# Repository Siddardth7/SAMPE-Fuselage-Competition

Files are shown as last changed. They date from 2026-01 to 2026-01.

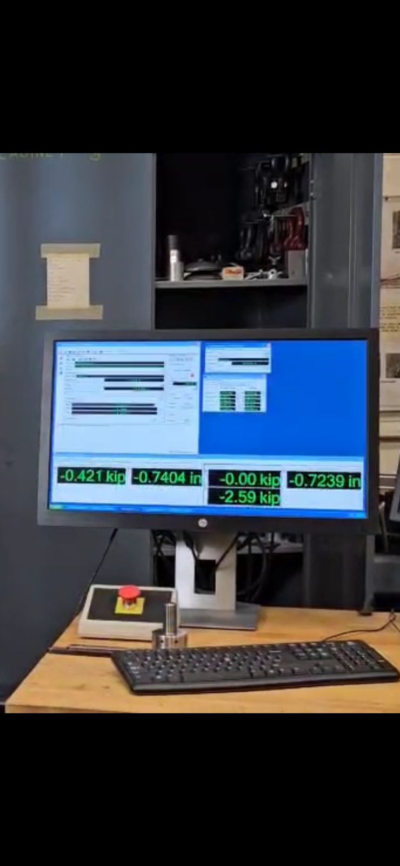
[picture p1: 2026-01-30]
images/utm_results.png

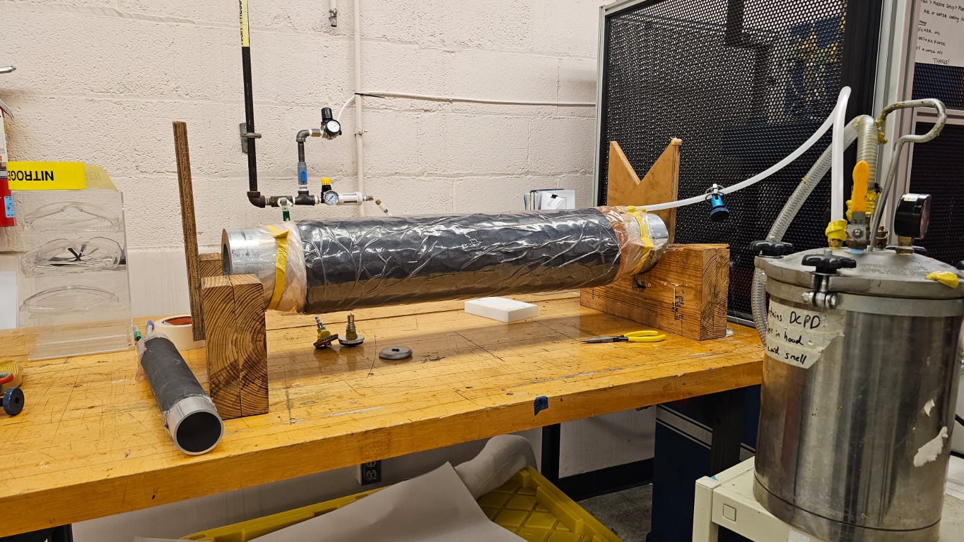
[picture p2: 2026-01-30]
images/vacuum_bagging_setup.jpg

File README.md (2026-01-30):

# SAMPE Fuselage Competition (2024‑2025)

## Overview

This repository contains the design, analysis and manufacturing records for a student‑built composite fuselage section created for the 2025 **SAMPE Student Chapter Fuselage Competition**.  The aim of the competition is to design, fabricate and test a glass‑fibre fuselage section that satisfies strict geometric constraints while withstanding at least **1 000 lbf** in three‑point bending with **< 1 inch** deflection.  Our team at the University of Illinois developed a sandwich fuselage using an E‑glass/epoxy skin and Nomex honeycomb core, optimized the laminate through analytical, numerical and experimental methods, built the part via vacuum‑bagged prepreg layup and autoclave cure, and validated the final structure in a universal testing machine.

## Objective

The project’s objectives were to:

* Comply with the **SAMPE fuselage design rules** (≥ 24 in length, 5.5–6 in diameter, four door cut‑outs, fibreglass only) and achieve a minimum **load capacity of 1 000 lbf** with less than **1 inch deflection**.
* Minimise weight while maintaining bending stiffness by selecting the appropriate number of plies, fibre orientations and core thickness.
* Design cut‑outs and stiffeners to minimise stress concentrations around the door openings.
* Develop a repeatable manufacturing process using prepreg layup, vacuum bagging and autoclave cure.
* Demonstrate the finished fuselage in a three‑point bending test and document performance.

## My Role

As part of a four‑person team I:

* Generated the **CAD model** of the fuselage and cut‑outs in SolidWorks and prepared drawings for manufacturing.
* Carried out **Classical Laminate Theory** calculations and wrote a **Python optimisation script** (`code/layup_optimizer.py`) to explore symmetric, balanced stacking sequences.  The program uses simulated annealing to maximise bending stiffness while controlling weight and enforcing symmetry and ply‑percentage constraints.
* Performed **finite‑element simulations** in Abaqus to estimate displacements and stresses for candidate layups; the chosen configuration produced ~2.5 mm displacement under design load.
* Evaluated manufacturing methods and selected **vacuum‑bagged prepreg layup with Nomex core** as the most cost‑effective process.  I documented risk sources (vacuum leaks, uneven pressure, resin pooling, porosity and environmental variability) and mitigation strategies.
* Led **layup and curing** in the composites lab, including core bonding, vacuum bagging, autoclave cure and trimming.  Process photos are available under the `images/` directory.
* Conducted the **three‑point bending test** and recorded load–deflection data.  The fuselage carried **≈ 2.6 kip** (≈ 2 590 lbf) at failure with **≈ 0.74 in deflection**, exceeding the competition requirements.
* Wrote the final design report, manufacturing report, risk assessment and presentation slides (see `docs/`).

## Technical Details

- **Materials:**
  - **Skins:** Woven **E‑glass/epoxy prepreg** (7781 E‑glass) chosen for cost and availability; S‑glass was analysed but deemed unnecessary after simulations predicted acceptable deflection with E‑glass.
  - **Core:** **Nomex honeycomb**, bonded between inner and outer skins to form a sandwich structure; core thickness selected based on stiffness–weight trade‑off.
  - **Adhesive:** Film adhesive (epoxy) used to bond core to skins.

- **Manufacturing & Analysis Methods:**
  - **Analytical design:** Classical Laminate Theory used to compute bending stiffness and first‑ply failure for candidate stacking sequences; results informed fibre orientation choices.  A **simulated annealing algorithm** (see `code/layup_optimizer.py`) searched for symmetric, balanced layups that maximise stiffness with minimum weight and 10 % ply‑orientation quotas.
  - **Finite‑element simulation:** 3D models built in **Abaqus** predicted a maximum displacement of ~2.5 mm for the selected layup under 1 000 lbf bending load.
  - **Manufacturing:**
    1. **Prepreg cutting:** Fibreglass prepreg, peel‑ply, release film, breather and vacuum bag were cut to size.  Core sections were cut from Nomex honeycomb.
    2. **Layup:** Layers were wrapped on a mandrel in the sequence [–45/0/45/90/Core/90/45/0/–45]s (symmetric with eight plies per face).  Light debulking was performed every four plies to remove air.
    3. **Core bonding:** Nomex core bonded to first skin using film adhesive; second skin laid on top.
    4. **Vacuum bagging:** The laminate stack was sealed with bag film, breather and tape; vacuum ports were attached, and the assembly was leak‑checked.
    5. **Autoclave cure:** Cured according to the prepreg cycle (ramp to cure temperature, hold, then cool).  A small amount of shrink tape provided radial compression.
    6. **Trimming & cut‑outs:** After cure, the fuselage was trimmed to 24 in length and four circular cut‑outs (≈ 2.5 in diameter) were machined per competition rules.
  - **Testing:** A **three‑point bending test** on a universal testing machine measured load and deflection.  The fuselage withstood **≈ 2.59 kip** before catastrophic failure with maximum deflection **≈ 0.74 in** at mid‑span, meeting the < 1‑inch deflection requirement at the specified 1 000 lbf load.

- **Tools & Software:** SolidWorks, Abaqus/CAE, Python (NumPy), Pandoc, universal testing machine (Instron), autoclave, vacuum pump and leak detector.

- **Standards & Constraints:** All work followed the **SAMPE Student Chapter Fuselage Contest Rules (2024‑25)**, which prescribe geometry (24 in minimum length; 5.5–6 in diameter), material restrictions (fibreglass only), four door cut‑outs per fuselage, and a design load of 1 000 lbf with ≤ 1 in deflection.

## Key Results

| Metric | Value / Outcome |
|---|---|
| FEA predicted deflection | ~2.5 mm at 1 000 lbf (Abaqus) |
| Final layup | [–45/0/45/90/Core/90/45/0/–45]s |
| Manufactured length | 24 in |
| Outer diameter | 6 in (5.5 in inner diameter) |
| Number of cut‑outs | 4 (2 per side, 2.5 in diameter) |
| Test load at failure | ≈ 2.59 kip (≈ 2 590 lbf) |
| Deflection at failure | ≈ 0.74 in |
| Weight | (not measured) |

## Engineering Challenges

* **Layup symmetry and balance:** Achieving a symmetric, balanced laminate with the required 0°, ±45° and 90° percentages while minimising ply count was non‑trivial.  The simulated annealing tool accelerated this search and identified an eight‑ply skin as optimal.
* **Vacuum integrity:** Minor leaks during vacuum bagging caused inconsistent consolidation.  The team used leak detectors and extra sealant tape to reduce porosity.
* **Core bonding:** Ensuring full adhesion between Nomex and skins without crushing the core required careful pressure control; shrink tape and breather materials assisted.
* **Stress concentration around cut‑outs:** The door cut‑outs introduced local stress raisers.  Choosing a woven prepreg and adding extra plies around openings mitigated these effects.
* **Testing fixture compliance:** Aligning the fuselage in the three‑point bending rig and preventing rotation during loading demanded fixturing modifications.

## What This Demonstrates

This project showcases skills and experience relevant to composites design and manufacturing roles:

* **Composite structures:** Deep understanding of classical laminate theory, ply orientation effects and sandwich construction.
* **Structural simulation:** Experience using Abaqus for FEA and interpreting deflection, stress and failure results.
* **Algorithm development:** Implemented a simulated annealing optimiser to automate layup selection under multiple constraints.
* **Hands‑on manufacturing:** Fabricated a composite fuselage via prepreg layup, vacuum bagging and autoclave curing; performed trimming and finishing.
* **Testing & validation:** Conducted a full‑scale three‑point bending test and analysed load–deflection behaviour against design requirements.
* **Risk management:** Identified and mitigated risks in vacuum bagging (leaks, uneven pressure, resin pooling, voids and environmental factors), documenting strategies for quality control.
* **Team collaboration & communication:** Coordinated with teammates to balance design, analysis and manufacturing tasks and produced comprehensive reports and presentations.

## Documentation

The `docs/` folder contains the full project documentation:

| File | Description |
|-----|---|
| **AE526_Final_Report.pdf** | Detailed design report including literature review, analytical calculations, FEA results and first ply failure analysis. |
| **Manufacturing_Report.pdf** | Comprehensive manufacturing report covering material selection, process evaluation, detailed prepreg layup steps, vacuum bagging procedure, autoclave cure schedule, risk assessment and mitigation strategies. |
| **Risk_Analysis.docx** | In‑depth risk and mitigation analysis for vacuum bagging, highlighting critical failure modes (bag leaks, uneven pressure, resin pooling, porosity, environmental factors) and recommended controls. |
| **Layup_Info.docx** | Literature survey summarising optimal ply counts, fibre orientations and symmetric/balanced stacking sequences for cylindrical fuselages. |
| **Competition_Rules.pdf** | Official SAMPE Student Chapter Fuselage Competition rules (2024‑25 edition). |
| **AE526_Presentation.pdf** | Slide deck summarising the design, manufacturing process and results for the course presentation. |

Process photos, FEA plots and test images are in the `images/` folder, while source code for the layup optimiser resides in `code/` and the SolidWorks model in `cad/`.

## Notes

* **NDA considerations:** All information provided here pertains to a student competition project and is publicly shareable.  No proprietary data or confidential sponsor information is included.
* **Future work:** Improving core modelling in simulations, exploring S‑glass skins for higher stiffness, performing additional testing to measure weight and failure modes, and refining cut‑out reinforcement methods.

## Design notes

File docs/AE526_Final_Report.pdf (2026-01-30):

AE526: Advanced Composites Manufacturing | Final Design Report

## FINAL DESIGN REPORT: FUSELAGE

Harsha Pandey, Ushasree Perakalapudi, Siddardth Pathipaka, Abhishek Iyer University of Illinois, Urbana-Champaign

The report presents the design and analysis of a composite fuselage section. The fuselage design adheres to specific constraints as laid out in the guidelines. Through theoretical calculations and simulations is done to determine the optimal design choices. Material selection and their justification is presented. Vacuum bagging was identified as the most suitable manufacturing method, considering its cost-effectiveness and ability to produce high-quality laminates. The results from the theoretical calculations, simulations are discussed. Future endeavors include optimizing the layup configuration and conducting simulations to assess the impact of door cutout positions on stress concentrations.

## 1. INTRODUCTION

NASA’s ACEE (NASA Aircraft Energy Efficiency) Program aimed to build and design composite components for commercial aircraft. Initial parts included fairing panels, spoilers, and skins. The Airbus A310 featured multiple composite parts, followed by the A320 which had an all-composite empennage. Composite materials improved performance in rotorcraft and general aviation. Boeing and Bell used composites in the V-22 airframe, reducing weight, costs, and part count. [46]. Recent advancements in aircraft materials and manufacturing have led to the development of innovative composites, such as Al-based, Mg-based, Ti-based alloys, ceramics, and polymers. These materials have exceptional properties and are widely used in the aerospace industry for cost reduction, weight reduction, and extended component service life. Composites are also used in military and commercial aircraft, as well as Unmanned Aerial Vehicles (UAVs). [47] Aircraft development in the early 1900s used sitka spruce and tightly woven wool fabric with varnish. Aluminum was experimented for weight savings due to limited power [Starke and Staley]. Strength-to-weight ratio was the primary criterion. While lightweight is important, current design considers time duration, fuel savings, range, and a history of multiple aircraft accidents. Now, new materials like high-strength aluminum alloys, titanium alloys, and carbon fiber-reinforced polymer composites have significantly enhanced performance. Material properties, chemistry, processing, and component design have led to substantial improvements. Different components have varying loading profiles, necessitating distinct design and materials selection. [48]

The advancements in material selection correspondingly warranted changes and advancements in manufacturing techniques, especially as composites were increasingly inculcated into the design of aircraft. The ATCAS program was sponsored by NASA with a focus on developing cost and weight-efficient composite technologies. Key manufacturing processes included Automated Fiber Placement (AFP) and Resin Transfer Molding for manufacturing of the frames and pultrusion for floor beams. Significant resources were invested into the program to optimize the manufacturing process to develop and optimize the processes for efficient and reliable fabrication of the composite structures. New manufacturing methods such as Outer-mold-line (OML) and inner-mold-line tooling (IML) were introduced to facilitate sandwich and stiffened-skin structures. The ATCAS program emphasized the importance of balancing and including the discussions of manufacturing considerations and techniques at the design stage itself to improve costing and throughput. [49]

In the following report, the design and analysis of a completely composite-based fuselage section is discussed. Theoretical and Analytical calculations are undertaken to ensure sound understanding and correlation between each other. Further, prospective materials (from the glass fiber family and relevant resin transfer system), fiber orientation, layups, manufacturing techniques and their effects on the strength of the composite are discussed. Analytical simulations and their agreement with theory is also shown. Finally, the manufacturing possibilities and methods are presented for the composite fuselage assembly. Both best cases as well as cost-effective manufacturing methods are shown.

## 2. METHODOLOGY

Design methodology usually started with gaining information on the market’s sentiments, and requirements. It is always recommended to gain an insight from the stakeholder’s point of view, as the new product generally caters to their requirements. Therefore, the stakeholder sentiments are obtained through a survey known as the Voice of the Customer (VOC), which aims to capture the most critical requirements the stakeholder thinks are an absolute necessity or the bare minimum in any new product introduced to the market. Next, theoretical calculation is undertaken based on metrics which are derived directly from the stakeholder’s feedback. This helps in the ideation of an initial iteration for the overall design, providing us with a complete baseline expectation of an agreeable design. Next, 3D simulations are done utilizing commercial software to get an understanding of how the product reacts to various loading conditions. Manufacturing methods are then discussed, in an ideal scenario as well as in the context of what is available at the Composites Manufacturing Laboratory at the University of Illinois.

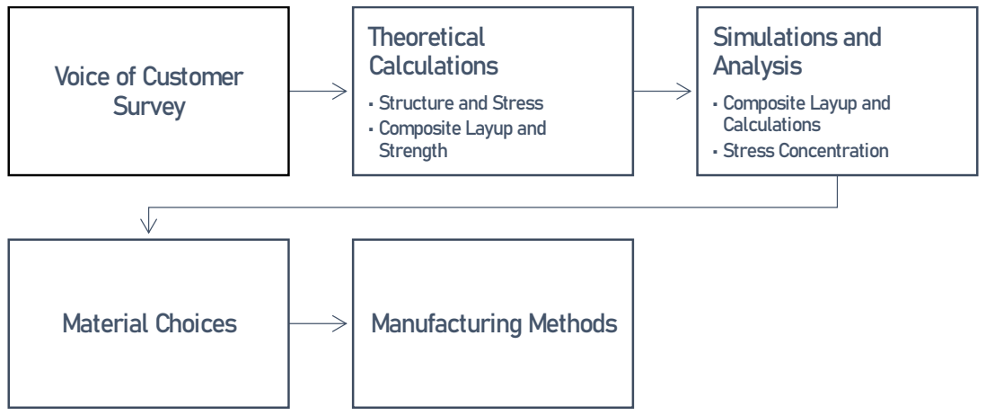
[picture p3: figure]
Voice of Customer Survey; Theoretical Calculations; • Structure and Stress • Composite Layup and Strength; Simulations and Analysis; • Composite Layup and Calculations • Stress Concentration; Material Choices; Manufacturing Methods

Figure 1: Methodology of the Fuselage Design Process

Figure 1 illustrates the overall design process which was followed for the development of the Fuselage.

## 3. IDENTIFYING REQUIREMENTS

There was very little need for a VOC survey in this context, as this design was being developed to be completely in compliance with rules and regulations laid out in the SAMPE Fuselage Design Competition guidelines.

As a result, the basic guidelines and broad constraints for the design were given as the following:

1. The design shall be capable of withstanding at least 1,000 lbf of load.
2. The design shall not deflect more than 1 inch in analysis at load requirement.
3. Fuselage shall be at least 24 inches in length.
4. Inner diameter shall not be less than 5.5 inches throughout the entire length of the fuselage.
5. Outer Diameter shall not be more than 6 inches throughout the entire length of the fuselage.
6. Fuselage shall include 4 cutouts at least 2 inches in diameter each.
7. Cutouts shall be at least 10 inches apart, and no more than 15 inches from each other’s closest edges.
8. Cutouts shall be at least 5 inches from the edge of the fuselage.
9. The fuselage shall be made of fiberglass.
10. A Nomex or Kevlar honeycomb core may be used.

The fuselage would be designed considering these initial design parameters.

## 4. CALCULATIONS

### 4.1 Theoretical Calculations

From the above provided requirements, we have a few values to utilize for our theoretical calculations. Consider the figure shown below:

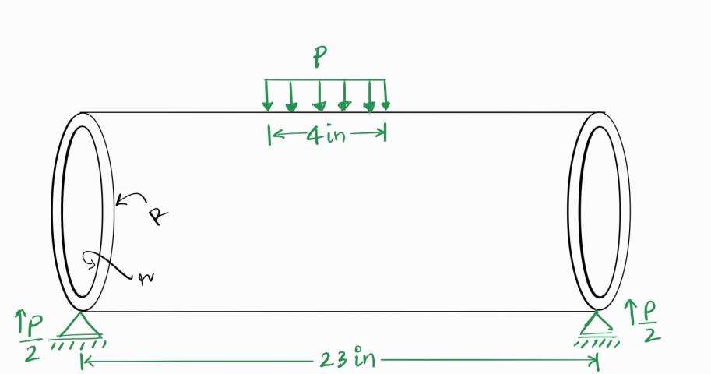
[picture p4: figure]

Indenter Load, P = 1000 lbf or 4448.22 N

Deflection, δ = 1 in or 25.41 mm

Length between the two supports of the Bending Fixture, L = 23 in or 584.2 mm

Inner Diameter, r = 5.5 in or 139.7 mm

Outer Diameter, R = 6 in or 152.4 mm

Length of the Fuselage = 24 in or 609.6 mm

The midpoint of the Fixture =

L
2

= 11.5 in or 292.1 mm

Following are the assumptions considered:

1. The material is Isotropic.
2. There are no laminates here, and the calculation done is for a solid hollow cylinder.
3. The distributed load while calculating has been normalized into a point load at the center of the fuselage.

Force measurement in tℎe Y direction (Tℎe Reaction force direction of

P
2

) is given by:

P − RA − RB = 0

or P −

P
2

−

P
2

= 0

or 4448.22 = P.
∴ tℎe equation is balanced. Tℎe Moment for B is given by:

4448.22 × 292.1 −

P
2

= 649662.531 Nmm

Tℎe neutral axis, y = 152.4 mm

I =

π
4

× [(76.2)

4 − (69.85)

4

] = 7783205.4141 mm⁴

∴ σ =

M × y
I

or σ =

(649662.531 × 76.2)
7783205.4141 | = 6.3604 MPa
We know tℎat δ = | FL
| 3
| 48 EI

or E =

FL

3
48 × δ × I

or E =

4448.22 × (584.2)

| 3
48 × 25.4 × 7783205.4141
or E = 93.4625 MPa

This initial calculation of the fuselage assumes a case of pure bending, typical for isotropic materials, e.g., steel. However, since the fuselage is going to be made of multiple layups of composite material, there will be out-of-plane forces involved making it imperative to consider the shear forces involved in future analyses.

Therefore, it is desirable that the effective Young’s modulus must incorporate not only the shear modulus but also the geometric factors (there are going to be cutouts in the final product) more accurately to reflect the behavior of the fuselage composite. Composites inherently show anisotropic properties, meaning stiffness and strength varying in direction. For the composite calculations executed, the team also felt that it was necessary to incorporate a factor of safety to account for some terms which were not considered. This also accounts for any other issues which may be encountered such as manufacturing defects, voids, and other environmental influences. The factor of safety also increases the fuselage’s ability to withstand loads.

Moreover, the requirement for cutouts introduces localized stress concentration around the perimeter of the cutout, which can be characterized by the stress concentration factor kt, which for circular geometries is approximately 3. This elevated stress must be factored into the bending stress to compute an effective bending stress especially when evaluating first ply failure.

### 4.2 Composite Analysis

The team followed reference [44] for the calculation of the composite layup. The paper was able to adapt the CLT usually used for a flat plate to the shape of a hollow cylinder among other shapes. The paper has experimental results to prove that the deflection was consistent with the analytical results up to a certain limit. The equation given by the paper for a Composite Tube for identifying the maximum deflection was:

wt = P {
Rm
16λEyWaT

[(3π − 8) (
Rm
e

+ 1) + (
kπEy

Gyz )] + [
L

3
48(EI)eq

+

L

4(GA)eq]}

wℎere e = Rm −

T
ln Rm + 0.5T
Rm − 0.5T

, λ = 6.74 (

RC
Rm

) + 1.01

(EI)eq = π (A11 − (
A12

2

A22)) Rm
3 + 2π (B11 −
B12

2
B22) +
π
Rm

(D66 −
(D26

2
)

D22 )

+ π (A55 − (
A45

2

A44)) Rm

Ey =

1
a22

∗ T

, Gyz =

1
a44

∗ T

The best composite layup would be the layup producing the least deflection of all. Therefore, the team created an iterative program in Python which iterated through all possible stack orientations, calculating the deflection for each iteration. Since there was also a core to be used in the layup, most of the available thickness was taken up by the core, allowing only for 4 plies to be used on each half of the composite fuselage.

Due to the inability of some composite packages available on python to consider a core material as part of the entire composite, two separate variations of the code were tried to solve the same problem of including the core as part of the ABD matrix. Silva et. al [45] devised a method in which they added the two ABD matrices of the core and the composite ply layup separately, along with a residual term added to adjust the entire equation. Instead of calculating the residual term as given, the team decided it was best to consider a factor of safety while calculating the equivalent Young’s modulus, as not including the term simply underestimated the modulus value.

The code based on the Composipy package and the equations from Zhu’s paper yielded differing results based on the material properties entered. It was observed that we cannot escape the issue of the core being considered as one of the plies in the composite. This is an issue as the core does not contribute much to the integral properties of the composite itself, contributing to reducing the shear loading and the load distribution of the composite. Its other inferior properties such as E1 and E2 are very low in comparison to the S-glass/Epoxy properties. The codes can be perused in the Appendix section.

## 5. SIMULATION ANALYSIS

To validate the results and to verify whether the theoretical results agree with real-world, a few simulations were carried out. ABAQUS was used, as it has a simplified interface to model the layup of composites. The simulations showed that the average deformation irrespective of the layups (two layups with the core in between: [0/45/-45/90]s and [0/0/0/0]s ) was in the range of 2.5 mm. The stress increased when the plies were changed to be angled. This could be due to the interlaminar shear stresses between each ply, which could increase due to the orientation.

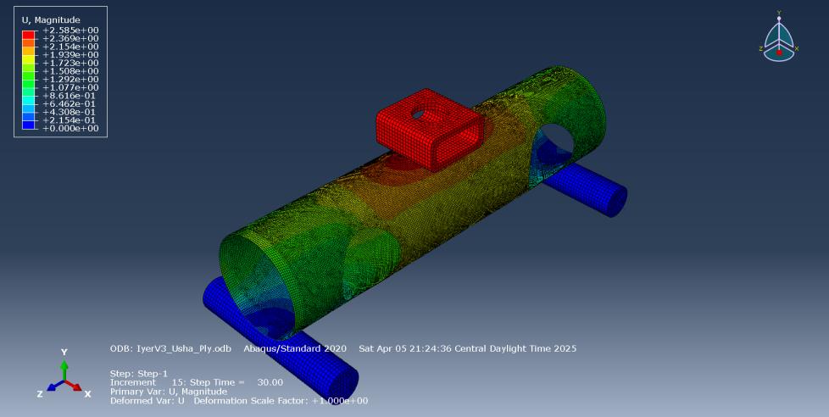
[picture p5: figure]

Figure 2: Maximum Displacement for the Ply Orientation [-45/0/45/90/Core/90/45/0/-45]

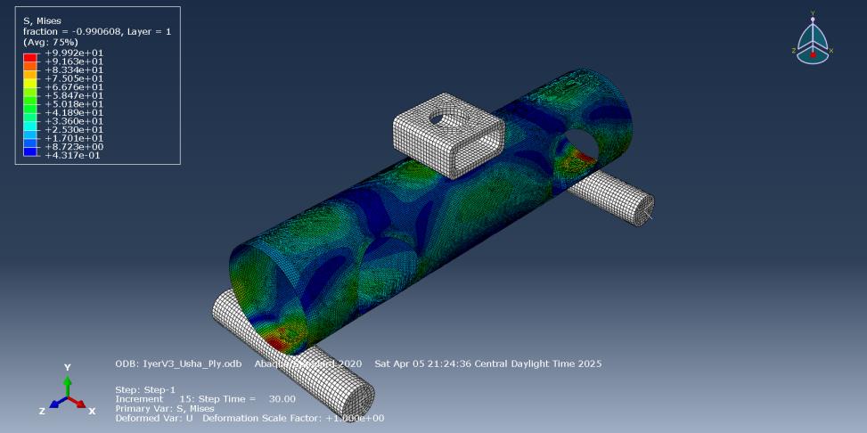
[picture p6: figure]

Figure 3: Stress Distribution for the Ply Orientation [-45/0/45/90/Core/90/45/0/-45]

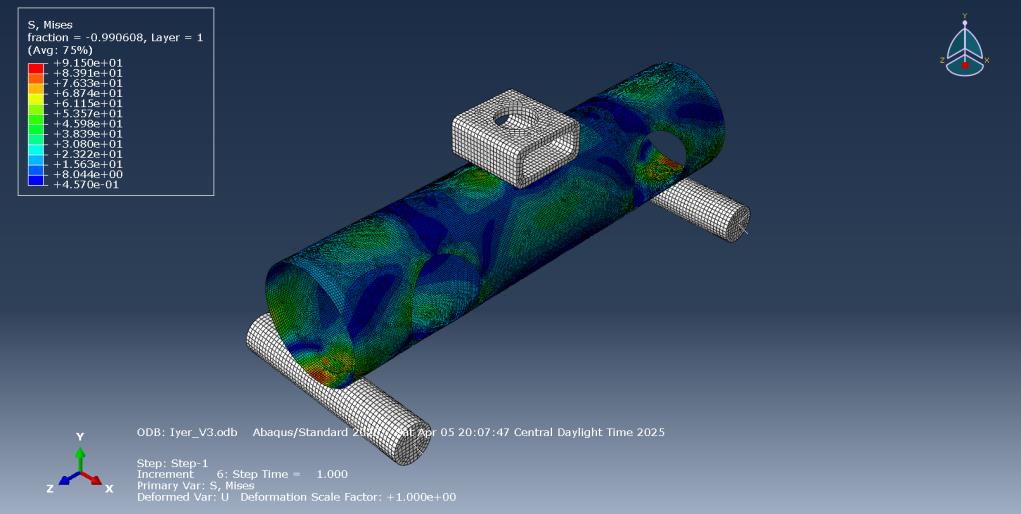
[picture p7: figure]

Figure 4: Stress Distribution for the Ply Orientation [0/0/0/0/Core/0/0/0/0]

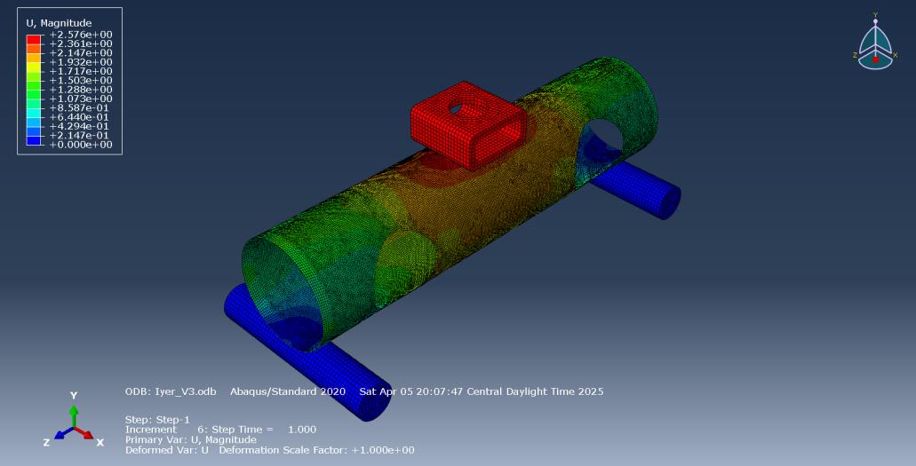
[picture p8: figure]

Figure 5: Maximum Displacement for the Ply Orientation [0/0/0/0/Core/0/0/0/0]

More research revealed that the core should have been modelled directly into the laminate assembly and therefore could have provided more accurate results. This should have been included previously, however due to a lack of time, it was not executed. Future work for the Manufacturing Report could include a simulation with respect to the same.

## 6. FIRST PLY FAILURE

A Glass fiber reinforced Epoxy laminate composed of 8 layers, including a core layer, was analyzed to determine the first ply to fail under bending loads by Tsai-Wu failure criterion. Each layer was defined by material properties in the local fiber axes and by an orientation angle measured relative to the global x-y axes. The procedure involved assembling the laminate stiffness matrices, computing curvatures from the applied bending moments, finding the global and then local stresses in each ply, and finally applying a failure criterion to identify the first layer that exceeds its allowable stress limits.

The analysis was implemented in Python using NumPy for matrix computations. The full stacking sequence, stiffness matrix assembly, curvature computation, and Tsai-Wu failure evaluation were automated. Stress and strain results were calculated for each ply under pure bending.Code can be found in the Appendix.

The compliance matrix S for each layer in local coordinates was constructed as follows. A unidirectional ply exhibits orthotropic behavior in its plane. Let E1, E2, G12, and ν12 be its In-plane moduli and Poisson ratio, respectively. Then the local compliance matrix is

The inverse of S was computed to give the local stiffness matrix Q.

A unidirectional layer oriented at an angle θ in the global x-y plane requires a transformation to obtain its global stiffness matrix Q̄.

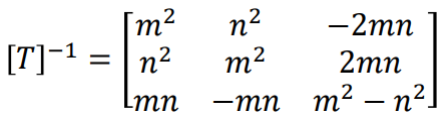
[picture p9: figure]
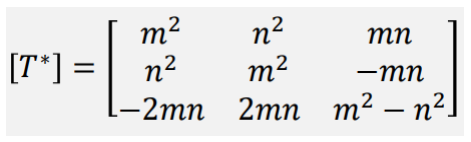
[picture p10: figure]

The laminate stiffness matrices A, B, and D were obtained by numerical integration through the thickness. Suppose the z coordinate is defined with the mid-plane at z = 0. For each layer k with a bottom surface hk−1 and a top surface hk, the stiffness integrals were carried out:

The sum of thicknesses from the bottom layer to the top produces the total laminate thickness, and the mid-plane defines z = 0.

In this case, one of the layers was designated as the core. Its thickness was larger than the surrounding plies, but its in-plane moduli were relatively small. This difference was reflected in its lower Q̄ contribution to A, B, and D. The resulting overall stiffness matrices included the entire stack, from bottom lamina through the core to the top lamina.

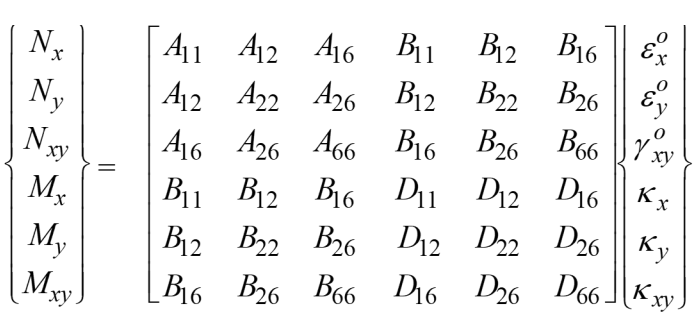
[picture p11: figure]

Being a symmetric laminate, the B vector was equal to zero. With A, B, and D known, a pure bending case with no in-plane loads was considered. The bending moment vector M was applied as per the loading conditions specified in the theoretical calculations.

The laminate curvature vector was solved from

In-plane strains at a distance z from the mid-plane were then calculated. For each ply, including the core, its local stiffness Q̄ was applied to this global strain to compute the in-plane global stress for each ply are calculated components in x and y directions plus xy shear.

A final transformation was then used to convert the global stresses to local fiber axes, that is σ1, σ2, and τ12.

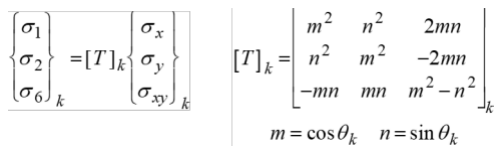
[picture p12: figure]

A ply failure criterion was applied to the local stress. The Tsai-Wu criterion, which can be stated in polynomial form as

Where,

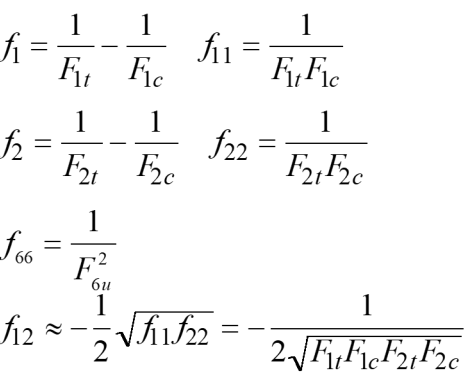
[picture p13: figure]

The strengths F1t, F1c, F2t, F2c, and F6 refer to tensile and compressive strengths in the fiber and transverse directions, plus in-plane shear strength. When the criterion was used, the index for each ply was computed in turn, starting from the bottom to the top. The first ply whose index exceeded 1 was designated as the first ply to fail. If the analysis included a core strength definition, that layer was also checked for in-plane failure; otherwise, the core was treated as having negligible in-plane strength and excluded from the failure checks.

This methodology accounted for each layer’s orientation, thickness, and stiffness, along with in-plane strengths in the fiber directions and shear. By computing local stresses under bending and testing them against these allowable limits, the analysis indicated which ply or layer including the core reached its critical stress level first.

A Classical Laminate Theory-based analysis was conducted to evaluate first ply failure under pure bending for various ply orientations. Multiple stacking sequences were examined, incorporating both symmetric and asymmetric configurations. Among the tested layups, the symmetric configuration [0∘

/45∘

/90∘

/45∘
]s, including a core layer, was found to be structurally effective under the applied maximum bending load. The stress distribution across the laminate thickness was assessed using the Tsai-Wu failure criterion, and no plies were found to fail at the specified loading conditions. Additionally, the computed maximum mid-plane deflection under this loading was 23 mm, indicating sufficient stiffness while maintaining failure resistance. This configuration can therefore be considered suitable for applications requiring both mechanical performance and reliability under flexural loads.

## 7. MATERIAL CONSIDERATION

### 7.1 Fiber Selection for Composite Fuselage

In composite structures, the choice of fiber reinforcement plays a critical role in determining mechanical performance, cost efficiency, and manufacturability. While high-performance fibers such as carbon fiber offer exceptional strength-to-weight and stiffness-to-weight ratios, their high cost often makes them impractical for certain applications. In this project, material selection was guided by established design guidelines, which specified fiberglass as the preferred reinforcement category. Among the available options, glass fibers were selected for further study as the primary reinforcement material due to their favorable balance of mechanical properties, cost-effectiveness, and availability. This makes them particularly well-suited for aerospace applications such as fuselage fabrication, where reliable performance must be achieved within budget and production constraints.

Glass fibers are recognized for their high tensile strength, good impact resistance, and ease of processing. Moreover, their widespread availability ensures a cost advantage over advanced fibers such as carbon or aramid. Among the glass fiber variants employed in aerospace applications, S-Glass and E-Glass are most frequently chosen due to their mechanical performance, cost-effectiveness, and widespread availability. These fibers fulfill demanding requirements for structural components, including high tensile strength, stiffness, and impact resistance.

Comparison of S-Glass vs. E-Glass:

Because of their extensive use and relevance to aerospace engineering, comparing S-Glass and E-Glass is crucial for identifying which fiber best satisfies the performance and cost targets of the fuselage design. This assessment focuses on key parameters such as tensile strength, stiffness, density, and impact resistance.

Mechanical Properties: Comparison of Key metrics from literature review :

Property | S-Glass | E-Glass | Advantage
Tensile Strength | 4600 Mpa | 3400 Mpa | +35% stronger
Elastic Modulus | 89 Gpa | 72 Gpa | +23% stiffer
Density | 2.53 g/cm³ | 2.54 g/cm³ | Almost same
Impact Resistance | High | Moderate | Better Durability

Table 1: Comparison of mechanical properties of S-glass and E-glass

Design-Specific Advantage:

S-Glass offers several distinct benefits over E-Glass for aerospace applications. Its 5.2% elongation, compared to E-Glass’s 4.7%, improves impact resistance in multidirectional laminates, while its higher fiber toughness reduces the risk of delamination during manufacturing. Additionally, its 30% greater compressive strength contributes to enhanced structural integrity around door openings and other high-stress areas.

After comparing S-Glass and E-Glass, S-Glass was chosen as the primary fiber for the fuselage design because of its superior mechanical properties. Its 35% higher tensile strength delivers a greater load-bearing capacity under bending forces, and the 23% increase in elastic modulus improves bending resistance while reducing deflection. Furthermore, its enhanced impact resistance makes S-Glass well-suited for regions experiencing stress concentrations or sudden loads, such as door cutouts or structural joints. Building on this selection, the next step involved evaluating different S-Glass variants to determine the most suitable option for the project.

Comparison of S-Glass Variants:

S-glass identified as the primary reinforcement material; the next step involves selecting a specific variant that best aligns with the fuselage design requirements. Different S-glass variants offer distinct properties optimized for various composite applications, where factors such as weave type, tensile strength, drapability, and cost can significantly affect the overall laminate performance. Comparing these variants enables the optimization of material selection by balancing design objectives and manufacturing processes. This below table examines three prominent S-Glass variants— AGY S-2 Glass, Hitex HS4 (SW220C), and Hexcel HexForce to determine which most effectively meets performance and manufacturing demands.

S-Glass Variants comparison table:

Variant | Tensile strength | Elastic Modulus | Density | Key Features | Relevance to our Project
AGY S-2 Glass | 4890 MPa | 89 GPa | 2.49 g/cm³ | Aerospace grade and High fatigue resistance | Best for load compliance Highest strength/stiffness. Reduces laminate thickness for outer diameter compliance.
Hitex HS4 (SW220C-90a) | 4200 MPa | 88 GPa | 2.53 g/cm³ | 4HS weave for drapability. Optimized for impact resistance. | Balanced choice. Stronger than E-Glass, easier to handle and cost-effective.
Hexcel HexForce S-Glass | 3500-4000 MPa | 85 Gpa | 2.63 g/cm³ | Plain weave. Options for pre-preg. Lower cost | Moderate Performance gains over E-glass and meets all project requirements.

Table 2: Comparison of properties of S-glass variants.

Based on the preceding comparison, AGY S-2 glass was selected for the fuselage design because of its superior mechanical properties. Its tensile strength of 4890 MPa, combined with an elastic modulus of 89 GPa, achieves an optimal stiffness-to-weight ratio. The lower density (2.49 g/cm³) further helps reduce overall laminate weight while maintaining structural integrity. In addition, its aerospace-grade quality and fatigue resistance make it particularly suitable for critical load-bearing sections, such as fuselage skins around door cutouts. Although other variants such as Hitex HS4 may offer advantages in drapability or cost, AGY S-2 Glass delivers the high-performance characteristics necessary to minimize laminate thickness while maximizing stiffness and strength.

### 7.2 Core Material:

Core materials play a crucial role in sandwich composite structures, providing a lightweight means of achieving the required strength, stiffness, and energy absorption. When developing high-performance sandwich structures, engineers commonly use materials like aluminum honeycomb cores due to their strength-to-weight ratio and cost-effectiveness. Polymer foam cores such as polymethacrylimide (PMI) foams are also frequently chosen for applications requiring superior mechanical properties, however the current guidelines constraints limit the choice to Nomex and Kevlar honeycomb cores. Hence are studied further to optimize the fuselage structure effectively.

Nomex and Kevlar honeycomb cores are frequently utilized in aerospace applications due to their favorable strength-to-weight ratios, fire resistance, and durability. Each variant presents distinct advantages and limitations, making a detailed comparison essential to identify the most suitable material for specific fuselage sections.

Property | Nomex Honeycomb core | Kevlar Honeycomb core
Shear Strength | 1.25 MPa (L-direction), 0.73 MPa (W-direction) | 1.75 Mpa (L-direction) (40% higher) . 1.02 MPa (W-direction)
Compressive Strength | 2.4 MPa | 3.36 MPa (40% higher than Nomex)
Density | 48 kg/m³ (Commercial grade) | 29-128 kg/m³ (Customizable based on size and thickness)
Cost | Lower (63.50 per sheet for 5mm thick and 48 kg/m³ | 20-30% higher than Nomex
Thermal Resistance | Service temperature: up to 180°C | Comparable to Nomex with better thermal stability under continuous exposure
Flame Resistance | Self-extinguishing to FAR 25.583 standards | Comparable to Nomex®, meets aerospace fire safety standards
Corrosion Resistance | Good moisture resistance with proper sealing | Excellent, resistant to chemical corrosion and environmental degradation.
Electrical Insulation | Moderate | High, suitable for electromagnetic shielding applications

Machining Difficulty | Moderate; easier to machine due to moderate rigidity

High; requires specialized tools due to abrasive nature and fragile cell walls.

Table 3: Comparison of properties of Kevlar and Nomex Honeycomb cores.

Based on the comparative analysis above, Nomex honeycomb cores are well suited for cost-sensitive applications demanding moderate strength and stiffness, making them ideal for fuselage components such as cabin floors and bulkheads. Kevlar honeycomb cores, in contrast, are more appropriate for high-stress regions requiring maximum shear strength and superior compressive performance. Strategic allocation of these materials ensures optimized structural efficiency and performance while complying with relevant design and material constraints

### 7.3 Introduction to Resin selection

Resins play a critical role in composite structures by binding reinforcing fibers, transferring loads between fibers, and providing protection against environmental factors. The resin matrix significantly influences the overall mechanical properties, chemical resistance, and thermal stability of composite materials. In aerospace applications, where high strength-to-weight ratios and durability are paramount, selecting an appropriate resin system is essential for maintaining structural integrity and optimal performance.

The resin systems selected for comparative analysis below were chosen based on their relevance to aerospace applications and their capability to satisfy specific performance criteria for composite fuselage structures. Epoxy, vinyl ester, polyester, and polyurethane resins were compared based on their mechanical properties, chemical resistance, and compatibility with S-glass fibers. By comparing these resin systems in terms of tensile strength, elastic modulus, shrinkage, chemical resistance and manufacturability, the analysis aims to determine the most suitable resin for fuselage design applications.

Rationale table for different types of resin systems:

Resin | Tensile Strength (MPa) | Elastic modul us (GPa) | Shrin kage | Chemical resistance | Compatibility with Fiber (S-Glass) | Performance Summary
Epoxy | 70-100 | 3-4 | <1% | Excellent resistance to moisture, solvents, and high temperatures (up to 150°C) | Fully compatible with S-glass; forms strong bonds with fibers due to high adhesion properties. Quick wet-out ensures uniform fiber impregnation | High strength and stiffness and strong bonding with S-glass minimizes delamination risks.
Vinyl Ester | 60-80 | 2.5-3 | <2% | Excellent resistance to acids, alkalis, and solvents | Fully compatible with S-glass; provides good fiber wet-out and adhesion | Affordable and tough but lower stiffness may result in higher deflection under load.
Polyest er | 40-70 | 2-2.5 | ~4% | Poor to moderate chemical resistance; susceptible to degradation over time in harsh environments | Limited compatibility with S-glass; weaker bonding compared to epoxy or vinyl ester | Limited mechanical performance
Polyure thane | ~50 | ~1.5 | <1% | Good resistance to solvents but limited durability | Compatible but does not provide strong bonding strength compared to epoxy or vinyl ester | Tough but lacks stiffness required for structural applications.

under cyclic
loads

Table 4: Comparison of properties of different resins

Based on the comparative analysis presented, epoxy resin demonstrates the highest mechanical performance among the evaluated options, aligning well with the requirements for composite fuselage designs. Its enhanced tensile strength and elastic modulus as detailed in above table ensure the stiffness and strength essential for load-bearing fuselage structures. Additionally, epoxy resin provides superior bonding capabilities with S-glass fibers effectively, minimizing the risk of delamination. Its compatibility with vacuum bagging techniques further contributes to a reliable and consistent manufacturing process. Although other resin systems possess certain advantages such as the cost effectiveness of polyester or the toughness characteristics of polyurethane, epoxy resin offers the most balanced and advantageous set of properties, meeting the demanding performance criteria required for aerospace fuselage applications.

### 7.4 Composite Layup Design:

Designing an effective composite layup for the fuselage is crucial for achieving the required structural performance while minimizing weight. This section presents the rationale behind the chosen layup design, examines the role of individual ply orientations and describes the methodology for optimizing the stacking sequence.

Role of Ply orientation in composite laminates:
Composite laminates derive their unique mechanical characteristics from the orientation of the individual plies. Each ply orientation addresses a specific structure need, contributing to the overall performance.
0° Plies: the primary function of 0° plies is to carry axial loads along the fuselage’s longitudinal axis. By aligning fibers at 0°, these plies maximize tensile and compressive strength in that direction, effectively resisting bending forces. However, an overreliance on 0° plies can concentrate stresses at ply interfaces, increasing the likelihood of delamination. Consequently, these plies are typically complemented by other orientations to mitigate stress concentrations. 45° Plies: plies oriented at 45° are essential for resisting shear forces and enhancing impact resistance. Shear stresses arise from in-plane loads acting parallel to a surface, and ±45° orientations distribute these forces more effectively. These plies also dissipate energy during impacts and dynamic loading, making them especially important in areas prone to shear forces or sudden loads, such as door cutouts or structural joints.
90° plies: Plies oriented at 90° provide lateral stability by resisting transverse loads perpendicular to the primary load direction. Although they contribute minimally to bending stiffness, these plies help maintain structural stability in cylindrical fuselage designs by counteracting hoop stresses from internal or external forces.

Multidirectional Layups:
Combining 0°, ±45°, and 90° plies in a symmetric, balanced configuration provides an optimal balance of stiffness, strength and weight. A commonly recommended stacking sequence is [0/45/90/45) s], which leverages 0° plies for axial stiffness, 45° plies for shear strength and impact resistance, and 90° plies for lateral stability. This approach minimizes stress concentrations and achieves more uniform load distribution.

Experimental evaluations show that while unidirectional laminates (12) offer high flexural strength, they are prone to brittle failures under transverse loads. Multidirectional laminates on the other hand, distribute stresses across various fiber orientations, thereby improving damage tolerance and reducing the risk of delamination.

Layers and thickness Optimization:
The total number of layers in a composite laminate significantly influences bending stiffness and overall mass. A minimum of three plies (approximately 0.53 mm in thickness) is necessary to prevent porosity and moisture ingress, thus preserving structural integrity. For aerospace fuselages exposed to bending and impact loads, 36-40 layers typically provide a suitable balance between stiffness and weight.

### Symmetry:

Symmetric and balanced layups are pivotal for minimizing residual stresses and preventing delamination during manufacturing or under operational loads. Symmetry helps distribute curing and thermal expansion stresses evenly throughout the laminate, reducing the likelihood of warping or twisting.

## 8. MANUFACTURING

### 8.1 Introduction to Manufacturing Plan Selection

This section analyzes potential manufacturing methods for fabricating a high-performance composite fuselage, integrating considerations of structural integrity, cost-effectiveness, design flexibility, and process scalability. Various methods are evaluated based on their alignment with design and performance objectives, and efficiency in resource usage. The final selection is justified through a structured decision matrix that accounts for critical factors identified in the literature review.

The manufacturing methods which were considered for this decision matrix are:
Change the order and write that which are most suitable in the beginning
1. Vacuum Bagging
2. Additive Manufacturing
3. Automated fiber placement (AFP)
4. Resin Transfer Molding (RTM)
5. Filament Winding
6. Hand Layup

The literature review identified vacuum bagging as the most efficient manufacturing method for composite fuselage structures due to its optimal balance of quality, performance, and cost-effectiveness. Vacuum bagging is good in producing high-strength, lightweight components characterized by uniform thickness and minimal defects, qualities particularly important in aerospace applications. To ensure a good understanding of the available manufacturing methods, this section briefly introduces each method, focusing on their respective processes, advantages, disadvantages, and suitability for fuselage manufacturing. Methods such as hand layup, resin transfer molding (RTM), filament winding, additive manufacturing (3D printing), and automated fiber placement (AFP) are studied to provide a comparative analysis that highlights their relative strengths and limitations within the context of fuselage manufacturing. This comparative overview establishes the rationale for selecting vacuum bagging as the preferred technique while recognizing the specific advantages of alternative manufacturing methods for specialized applications.

Vacuum Bagging

The vacuum bagging process involves sealing layers of fiber under a vacuum bag to ensure uniform pressure during curing. This technique is designed to consolidate the laminate effectively while simultaneously removing excess resin and trapped air. By creating a controlled environment under vacuum pressure, the fibers are compressed uniformly, resulting in a more compact and cohesive structure. The vacuum bag acts as a barrier, maintaining consistent pressure throughout the curing process, which is critical for achieving optimal laminate quality.

Vacuum bagging offers several advantages over traditional hand layup methods. One of its key benefits is improved consolidation, which leads to reduced void content within the laminate. This results in a stronger and more durable composite structure. Additionally, vacuum bagging provides more consistent thickness across the laminate compared to hand layup techniques, ensuring uniformity in structural properties. The method also delivers higher strength-to-weight ratios and more consistent quality, making it particularly beneficial for medium-sized fuselage structures. However, there are some disadvantages associated with this process. Vacuum bagging requires additional equipment such as vacuum pumps and bagging film, which can increase costs slightly compared to hand layup methods. Furthermore, operator proficiency is essential to prevent leaks during the process, as the maximum pressure achievable is limited to atmospheric pressure (approximately 14.7 psi).

Vacuum bagging is commonly employed for primary fuselage structures where moderate strength and weight efficiency are essential. Its ability to produce consistent and high-quality laminates makes it an ideal choice for applications requiring reliable performance in medium-sized composite components. While it may not be suitable for all manufacturing scenarios due to its equipment requirements and cost considerations, vacuum bagging remains a preferred method for achieving structural integrity in aerospace applications where strength-to-weight ratios are critical.

Additive Manufacturing (3D Printing):

Additive manufacturing, commonly referred to as 3D printing, is a process in which composite materials, such as carbon fiber-reinforced thermoplastics, are deposited layer by layer to construct parts. This technique eliminates the need for extensive tooling and allows for the precise fabrication of components directly from digital designs. By building parts incrementally, additive manufacturing offers a highly controlled and efficient method for producing composite structures while minimizing material waste.
The advantages of additive manufacturing are significant, particularly in terms of design flexibility. This method enables the creation of intricate geometries and integrated features that would be challenging or impossible to achieve with traditional composite fabrication techniques. Additionally, additive manufacturing excels in rapid prototyping, allowing engineers to quickly test and iterate designs with minimal material waste. Despite these benefits, there are notable disadvantages. The mechanical properties of parts produced through additive manufacturing may be inferior to those achieved using conventional composite methods. Furthermore, this process is generally restricted to smaller scale parts and offers limited material options compared to traditional techniques.

Additive manufacturing is particularly suited for prototyping fuselage components that require complex internal structures or lightweight core designs. Its ability to produce intricate geometries and lightweight parts makes it ideal for applications where design complexity and efficiency are prioritized. While it may not be suitable for large-scale production or high-performance structural components due to its limitations in mechanical properties and material selection, additive manufacturing remains a valuable tool for innovation in aerospace prototyping and lightweight design.

Automated Fiber Placement (AFP):

Automated Fiber Placement (AFP) is a highly advanced manufacturing process that utilizes robotic systems to deposit prepreg tapes onto a mold with exceptional precision. This process involves controlling fiber orientation and thickness to ensure optimal structural performance. The fibers, typically carbon or glass, are pre-impregnated with resin and placed in narrow strips, known as "tows," which are compacted and heated during the deposition process. The robotic system ensures repeatable accuracy, enabling the fabrication of complex geometries and high-quality composite structures. AFP is widely employed in aerospace manufacturing to create large-scale components such as fuselage sections and wing spars, where precise material placement is critical for achieving desired mechanical properties [3] (https://en.wikipedia.org/wiki/Automated_fiber_placement)[5] (https://www.addcomposites.com/post/overview-of-automated-fiber-placement-process)[7]. (https://www.wevolver.com/article/what-is-automated-fiber-placement-afp-in-composites-manufacturing)

AFP offers numerous advantages that make it a preferred method for composite manufacturing in aerospace applications. Its unmatched precision in fiber placement minimizes material waste and ensures consistent quality across large, complex structures. This precision also allows for optimized fiber orientations, enhancing the strength-to-weight ratio of the final product. Additionally, AFP significantly reduces production time compared to manual methods, as robotic systems can operate continuously with minimal downtime [2] (https://www.addcomposites.com/post/what-is-automated-fibre-placement-afp)[5] (https://www.addcomposites.com/post/overview-of-automated-fiber-placement-process)[6]. (https://www.wanlitex.com/news/understanding-the-principles-advantages-disa-77085396.html) However, AFP comes with notable disadvantages. The equipment and operational costs are extremely high, requiring substantial capital investment. Furthermore, skilled operators and programming expertise are essential to manage the system effectively and prevent defects such as material wrinkling or gaps during the layup process [4] (https://compositeskn.org/KPC/A303)[6] (https://www.wanlitex.com/news/understanding-the-principles-advantages-disa-77085396.html)[7]. (https://www.wevolver.com/article/what-is-automated-fiber-placement-afp-in-composites-manufacturing)

AFP is particularly suitable for manufacturing large composite structures in the aerospace industry, where weight optimization and repeatability are paramount. Its ability to produce high-performance laminates with precise fiber orientations makes it ideal for fuselage sections, wing spars, and other critical components requiring superior mechanical properties. While its high cost may limit its use outside of industries that can justify such investments, AFP remains an indispensable technology for applications demanding lightweight yet durable structures, such as commercial aircraft and spacecraft

Resin Transfer Molding (RTM):

Resin Transfer Molding (RTM) is a composite manufacturing process that involves positioning dry fibers within a closed mold and injecting resin under pressure to impregnate the reinforcement thoroughly. The resin, often combined with catalysts, flows into the mold cavity to saturate the fiber preform, ensuring uniform distribution and complete impregnation. Once the resin cures, the mold is opened, and the finished component is removed. RTM enables precise control over fiber orientation and resin content, making it suitable for producing high-performance composite parts with excellent dimensional accuracy and surface finishes. This process is widely used in industries such as aerospace, where lightweight and durable components are essential.

RTM offers several advantages that make it a preferred method for composite manufacturing. It produces high-quality parts with consistent dimensions and excellent surface finishes on both sides of the component. The process is particularly well-suited to complex geometries and integrated features, such as door cutouts, due to its ability to mold intricate shapes with tight tolerances. Additionally, RTM minimizes material waste by allowing near-net-shape production, reducing post-processing requirements. However, there are some disadvantages associated with RTM. The initial setup cost is high due to the need for specialized mold fabrication, which can be a barrier for small-scale production or prototyping. Moreover, achieving optimal results requires careful control of processing parameters and skilled operators.

RTM is ideal for manufacturing high-performance fuselage sections that demand tight tolerances and reduced post-processing. Its ability to produce lightweight yet durable components make it particularly valuable in aerospace applications where structural integrity and weight optimization are critical. While its high initial costs may limit its use in certain scenarios, RTM remains indispensable for applications requiring precision-engineered composite parts with complex geometries and superior mechanical properties

Filament Winding

Filament winding is a composite manufacturing technique that involves winding continuous fibers, such as carbon, glass, or aramid, onto a rotating mandrel. The fibers are impregnated with resin either before or during the winding process to ensure proper bonding and structural integrity. The mandrel rotates while a carriage system moves horizontally, laying down the fibers in predetermined patterns to achieve the desired orientation and thickness. Once the winding is complete, the resin is cured using heat or other methods, and the mandrel is removed to leave behind a hollow composite structure. This process is particularly effective for creating cylindrical or spherical components with high mechanical strength and precision.

Filament winding offers several advantages, making it an efficient and reliable method for composite manufacturing. It provides high hoop strength due to its ability to optimize fiber placement for cylindrical shapes, making it ideal for pressure vessels or structures subjected to hoop loading. The process efficiently utilizes continuous fibers, resulting in strong and lightweight components with minimal material waste. Additionally, filament winding is highly automated, ensuring repeatable quality and reducing labor costs. However, there are limitations to this method. It is primarily restricted to axisymmetric geometries and cannot accommodate complex shapes with openings, such as fuselage sections with integrated features. Furthermore, filament winding requires specialized equipment, which can be costly to acquire and operate.

Filament winding is particularly suitable for manufacturing fuselage tubes or pressure vessels that demand significant hoop strength and relatively simple geometries. Its ability to produce lightweight yet durable components make it an excellent choice for applications where internal pressure resistance is critical. While its geometric constraints limit its use for more intricate designs, filament winding remains a preferred method for producing high-performance cylindrical structures in industries such as aerospace, automotive, and industrial manufacturing.

Hand Layup

The hand layup process is one of the simplest and most widely used methods for composite manufacturing. It involves manually placing fiber reinforcements, such as fiberglass or carbon fiber, onto a mold that has been prepared with a release agent to prevent sticking. Resin is then applied using brushes, rollers, or similar tools to impregnate the fibers thoroughly. Additional layers of reinforcement and resin are added sequentially until the desired thickness is achieved. Once the layup is complete, the composite is allowed to cure, either at room temperature or under controlled conditions, before being removed from the mold. This process is straightforward and requires minimal equipment, making it accessible for small-scale production and prototyping.

Hand layup offers several advantages due to its simplicity and low initial cost. It requires minimal equipment and is highly adaptable, allowing for flexibility in layup orientation and design modifications. These characteristics make it particularly suitable for small-scale fuselage sections or prototypes where precision is not critical. However, the process has notable disadvantages. It is labor-intensive and time-consuming, which limits its efficiency for larger-scale production. Additionally, because it relies heavily on manual labor, there is a higher risk of defects such as inconsistent fiber alignment, elevated porosity, and air voids. These issues can result in parts with variable mechanical properties and inconsistent thickness.

The hand layup process is most suitable for producing small fuselage prototypes or non-critical components where tight tolerances and high mechanical performance are not required. Its low cost and adaptability make it an attractive option for experimental designs or projects with limited budgets. However, for applications requiring consistent quality or high production volumes, alternative methods such as vacuum bagging or resin transfer molding may be more appropriate. Despite its limitations, hand layup remains a valuable technique for specific use cases in composite manufacturing due to its versatility and accessibility.

Rationale with decision matrix:

The selection of the manufacturing method was conducted through a decision matrix which is employed to systematically evaluate each technique against a predefined set of criteria. This structured approach ensures an objective comparison by assigning weights to these criteria based on their relative importance in fuselage manufacturing, including factors such as cost efficiency, Compliance to rules, Quality of Finished Product, and Flexibility in Design. Each manufacturing method is subsequently scored against these weighted criteria to quantify its overall performance. This structured framework facilitates identifying the most effective manufacturing method while offering transparent and justifiable reasoning for the selection process.

Criteria | Weight | Justification
Cost | 3 | Budget constraints necessitate minimizing material, tooling, and labor costs.
Manufacturing Time | 4 | Efficient and timely production is a fundamental requirement
Quality of Finished Product | 5 | As the part needs to withstand load requirement and needs to have minimum defects to produce High quality product
Implementation | 4 | The method must be feasible given available skills, equipment, and resources.
Flexibility in Design | 4 | The ability to produce complex geometries (e.g., fuselage cutouts) is advantageous.
Compliance to rules | 5 | Must comply with established guidelines, requirements, and regulations.

Decision Matrix:

The decision matrix below shows the evaluation of various manufacturing methods for fuselage production. Each method is assessed against key performance criteria, with weights assigned to reflect their relative significance in fuselage manufacturing. This comparative framework enables a clear and systematic analysis, supporting the identification of the most appropriate manufacturing technique for fuselage applications.

Method | Cost (4) | Manufa cturing Time (4) | Quality (5) | Implementati on (4) | Flexibili ty (4) | Complia nce (5) | Total Weighted score
Hand Layup | 5 | 2 | 2 | 5 | 2 | 5 | 91
Vacuum Bagging | 4 | 3 | 4 | 4 | 3 | 5 | 105
RTM | 2 | 4 | 4 | 2 | 4 | 4 | 88
Automated Fiber Placement | 1 | 5 | 5 | 1 | 5 | 4 | 93
Filament Winding | 3 | 3 | 4 | 3 | 2 | 5 | 89
Additive Manufacturi ng | 2 | 4 | 4 | 3 | 5 | 5 | 101

Table 5: Decision matrix of comparing various manufacturing methods against criteria

Based on the outcomes of the comprehensive decision matrix, vacuum bagging is identified as the most suitable manufacturing method for composite fuselage production. This technique offers an optimal balance of cost efficiency, manufacturing quality, and ease of implementation, aligning well with the rigorous performance requirements of the fuselage. Although additive manufacturing presents significant potential for producing complex geometry and innovative designs, its current limitations in scalability and mechanical performance render it less practical for mid-scale fuselage fabrication. The established reliability of vacuum bagging, along with its capacity to deliver consistent and high-quality results, reinforces its selection as the preferred method for manufacturing high-performance composite fuselages.

### 8.2 Planned processing steps involved in vacuum bagging method:

The following section provides a systematic explanation of each step involved in the manufacturing approach, from material preparation and fiber layup to vacuum sealing and curing. This step-by-step outline illustrates how the method is implemented to optimize structural performance, minimize manufacturing defects, and fulfill the requirements associated with fuselage production.

### Mold Preparation:

1. Start by Thoroughly clean the Mold surface with acetone or other solvent
2. Apply Coating or releasing agent at least 2-3 times to avoid sticking and allow each coat to dry completely.
3. Lay Down a layer of mold release film or peel ply which can help in part removal and surface finish.

### Cutting and Material preparation:

1. Cut the fiberglass fabric to required dimensions allow extra for trimming
2. Pre-cut peel ply, release film, breather material, and vacuum bagging film

### Layup:

1. Apply the first layer of fiberglass fabric on to the mold ensuring no wrinkles.
2. Use a roller to remove any air bubbles.
3. Continue adding layers according to layup configuration [0/90/(±45)2s].
4. Between the layers use a roller to make sure there aren't any air bubbles.
5. Place peel ply over the final layer of fiberglass.

### Vacuum Bagging setup:

1. Apply release film over the peel ply.
2. Add breather material over the release film.
3. Position vacuum ports and tubing for even resin distribution.
4. Drape vacuum bagging film over the entire layup
5. Seal edges with sealant tape, making sure it's airtight seal.

### Resin Preparation:

1. Calculate the required amount of resin based on your layup.
2. According to our manufacturer’s specifications mix epoxy resin and hardener.
3. Degas the resin mixture in a vacuum chamber to remove air bubbles.

### Resin Infusion:

1. Connect the vacuum pump and create an initial vacuum to check for any leaks.
2. Once sealed, inject resin mixture through inlet ports.
3. Monitor the resin flow, make sure it's evenly distributed across the layup.
4. Clamp off resin inlet once resin covers entire layup and wet-out is achieved.

### Curing Process:

1. Maintain vacuum throughout the curing cycle
2. For heated cure, place the mold in an oven and for room temperature cure allow the part to cure for 24-48 hours.
3. Follow the resin manufacturer’s recommended cure cycle for time and temperature of curing.
4. Adjust vacuum pressure as needed or as recommended during cure.

### Post-curing:

1. Remove the part from the mold after curing
2. Place the part in an oven for any post-curing if it's recommended by the manufacturer.

### Finishing:

1. Trim excess material using cutting tools.
2. Use sandpaper to smooth the edges for a clean finish.
3. Cut out the door opening according to our calculations.
4. Sand the door openings for a smoother finish.

### Quality control:

1. Measure the dimensions to ensure they match with our calculations and meet our competition rules.
2. Perform visual inspection for any surface defects.
3. Do the tap testing to check for any voids or delamination.

### 8.3 Identified key risks with impacts

### Identification of potential risks in selected manufacturing method:

Vacuum bagging is a widely used and reliable method for manufacturing composite fuselages. However, certain risks remain inherent to the process. These risks arise from process complexity, environmental factors, and the need for precise execution. Each potential risk is described below, focusing on its relevance to fuselage manufacturing and accompanied by an assessment of its likelihood and impact.

### Potential Risks in Vacuum Bagging:

Leaks or Bag failures:
Leaks in the vacuum bag or improper sealing compromise vacuum pressure, leading to insufficient laminate consolidation. Poor compaction can result in voids, reduced mechanical properties, and potential failure under load. Studies indicate that vacuum bag leaks have the greatest negative impact on composite part quality.
Consistent compaction is essential for maintaining uniform strength and stiffness in fuselage sections. However, the likelihood of vacuum bag leaks remains high, primarily due to manual sealing errors or defects in the bag material. When such defects occur, they can have a significant impact, often leading to scrapped parts or a reduction in structural integrity.

Uneven Pressure distribution:
Improper placement of breather material or wrinkles in the vacuum bag can create uneven pressure during curing, resulting in localized defects such as resin pooling or dry spots. These flaws weaken the laminate and may form critical failure points.
Uniform pressure distribution is essential for achieving consistent fiber-to-resin ratios across large fuselage components. The likelihood of issues in this area is medium, as outcomes are highly dependent on operator skill and the precision of the setup. The impact, however, is high—any weak spots resulting from inconsistent pressure can lead to delamination or failure under stress.

Resin pooling or dry spots:
Incorrect resin application or uneven flow during infusion can cause excess resin (pooling) or insufficient resin (dry spots), reducing laminate stiffness and increasing the risk of delamination. In fuselages, such inconsistencies can compromise reliability under dynamic loads.
The likelihood of issues in this area is medium, as it is influenced by factors such as resin viscosity, flow media design, and operator experience. The impact is also medium, as these issues can reduce the overall strength and durability of the composite structure.

Surface Finish defects:
Variations in vacuum pressure or curing conditions may produce surface imperfections such as wrinkles or entrapped air. On a fuselage, surface defects could affect both aerodynamic performance and quality, factors that often hold weight in competitions.
A smooth surface finish is important for both aerodynamic efficiency and visual appeal. The likelihood of surface finish issues is low, as they can generally be mitigated through careful setup and ongoing monitoring. The impact is medium—while such imperfections typically have limited structural consequences, they could influence competition scoring.

Environmental Factors:
Fluctuations in temperature and humidity during curing can affect resin viscosity and curing times, potentially causing incomplete polymerization or inducing thermal stresses in the laminate Controlled curing environments are critical for maintaining consistent mechanical properties throughout large fuselage structures.
The likelihood of issues arising in this area is medium, as they are heavily influenced by local workshop conditions and the quality of available equipment. The impact is also medium, as inadequate curing may reduce part consistency and affect long-term durability.

Likelihood and Impact Assessment: The likelihood and impact of each risk were assessed based on industry data and practical experience:

Risk | Likelihood | Impact | Overall Risk level
Leaks or Bag failure | High | High | Critical
Uneven Pressure distribution | Medium | High | Significant
Resin pooling/Dry spots | Medium | Medium | Moderate
Surface Finish Defects | Low | Medium | Low
Environmental Factors | Medium | Medium | Moderate

Table 6: Likelihood and Impact Assessment

### 8.4 Mitigation strategies for the Risks identified:

Mitigation Strategies for Vacuum Bagging Risks:

Leaks or Bag Failures:
Mitigation strategies include the use of automated leak detection systems, such as pressure decay sensors or ultrasonic leak detectors, to identify leaks during setup. Implementing pre-engineered vacuum bag kits with pre-cut materials, such as those offered by Velocity Composites PLC, can help minimize manual errors. Additionally, applying redundant sealing methods—using double-sided adhesive tape and silicone sealant at critical joints—can further reduce the risk of leaks.

Uneven Pressure Distribution:

Mitigation measures include optimizing breather material placement by using flow simulation software to design effective resin flow paths. This helps ensure even distribution and efficient compaction. Additionally, integrating automated pressure monitoring with real-time sensors can help maintain uniform compaction throughout the curing process.

Resin pooling/ Dry Spots:
Mitigation strategies involve simulating resin infusion using tools such as PAM-RTM or ANSYS to predict and prevent the formation of dry spots. Additionally, implementing controlled resin application through metered mixing systems helps maintain consistent resin viscosity and flow rates throughout the process.

Surface Finish defects:
Mitigation involves maintaining controlled curing conditions, with stable temperatures between 20–25°C and humidity levels below 60% during the curing process. Additionally, applying peel ply fabric can help achieve smooth surface finishes.

Environmental Factors:
Mitigation includes using a climate-controlled workspace, supported by portable dehumidifiers and heaters, to stabilize workshop conditions. Additionally, selecting resins with longer pot lives can help accommodate variability in the environment during processing.

Risk Prioritization Matrix (Likelihood Vs Impact)
The 5x5 Matrix below asseses risks based on their likelihood and Impact, guiding resource allocation for mitigation:
Impact → Likelihood ↓ | Very Low (1) | Low (2) | Medium (3) | High (4) | Very High (5)
Almost Certain (5) | | | | Leaking of Vacuum bag/Imperfect Seal
Likely (4) | | | | Uneven Pressure
Probable (3) | | Environmenta l factors | Resin Pooling
Unlikely (2) | Surface Finish Defects

Very Unlikely (1)

Table 7: Risk Prioritization Matrix (Likelihood Vs Impact)

The risk assessment matrix for the manufacturing process identifies and categorizes potential issues based on their severity and likelihood of occurrence. The most critical risk is the possibility of leaks during resin infusion, which could prevent the vacuum bag from holding vacuum and compromise the structural integrity of the part. Significant risks include uneven pressure distribution during curing, which may lead to delamination or inconsistent mechanical properties. Moderate risks such as resin pooling are also noted, as they can cause local increases in weight or reduced fiber volume fraction. Low risks include surface finish imperfections, which primarily affect aesthetics rather than structural performance. Lastly, below moderate risks such as minor environmental factors (e.g., ambient temperature or humidity) are considered less impactful but still monitored to ensure process consistency. This categorization helps prioritize mitigation strategies and informs quality control measures during manufacturing

## 9. Final Decision on Manufacturing/Literature Review:

The team would like to move ahead with Manufacturing.

## 10. CONCLUSION

A comprehensive design and analysis of a composite Fuselage was presented within the given requirements of the SAMPE design competition. A baseline design derived through requirements was iterated upon thorough theoretical calculations and a thorough literature review. A comprehensive understanding of the behavior and mechanics of the fuselage were obtained through theoretical and simulations. The fuselage structure was engineered using a strategic combination of S-Glass fibers (AGY S-2), Nomex and Kevlar honeycomb cores, and epoxy resin, resulting in a composite that balances rigidity, impact resistance, and cost-effectiveness. The use of a balanced layup sequence [0°/45°/90°/45°]s further enhanced load transfer efficiency and minimized risks associated with interlaminar failure.

The iterative approach adopted throughout the design process allowed for continual refinement of geometry and material configuration, ultimately yielding a solution that meets both strength and stiffness requirements while minimizing weight.

Simultaneously, Manufacturing considerations were also central to the design process. Vacuum bagging was selected for its ability to produce consistent, high-quality laminates, with specific mitigation strategies implemented to address known manufacturing challenges such as vacuum leakage and pressure inconsistency.

However, the team believes that there are still many avenues for research and further understanding which can be done in the future.

1. Further Optimization study of the Layup of the Composite is required. This is because the optimization carried out in the current report is conservative due to the various assumptions listed in the report during the calculation phase of the design. Further refinement could be done in this area by utilizing better optimization techniques.
2. Further, the simulation done does not consider the different positions of the door cutouts which can be optimized to decrease stress concentration factor.
3. Additionally, the simulation does not consider the cavities present in a honey-comb structure as the core itself is considered a ply in the overall laminate make-up. This is causing an over-prediction of the minimal displacement achieved. Therefore, further study needs to be done in this area by assuming an accurate morphology of the honeycomb structure.
4. Proposed manufacturing methods are based completely on ideal conditions, and on the basis that there was access to the best method available, and the Apparatus and Constraints placed on the team due to the availability of machinery on the campus were not considered for this report. The Manufacturing Report should be more in line with the processes available to us on campus.

DISCLOSURE: The team would like to disclose that there has been limited and responsible use of Artificial Intelligence agents in the documentation of this project, and as a glorified search engine to identify relevant academic papers efficiently. After obtaining responses, the team carefully verified and vetted all information which has been presented in this report.

## 11. REFERENCES

1. https://jpscm.com/products/e-glass-s-glass/
2. https://www.smicomposites.com/comparing-e-glass-vs-s-glass-key-differences-and-benefits/ (https://www.smicomposites.com/comparing-e-glass-vs-s-glass-key-differences-and-benefits/)
3. https://www.compositesone.com/product/advanced-reinforcements/s-glass/
4. https://www.hitex-composite.com/products/S-Glass-Fabric.html
5. https://www.agy.com/aerospace-2/
6. https://vectorply.com/reinforcement-fibers/
7. https://www.wehausa.com/s-type-fiberglass-s/2655.html
8. https://www.dupont.com/fabrics-fibers-and-nonwovens/nomex-for-aerospace.html
9. https://www.dupont.com/fabrics-fibers-and-nonwovens/kevlar-for-aerospace.html
10. https://cacomposites.com/core-materials/kevlar-honeycomb-cores/
11. https://axiommaterials.com/products/aerospace-grade-nomex-honeycomb/
12. https://www.toraytac.com/media/5527e573-2e72-4aa4-bda7-5a49a20fef06/guunTA/TAC/Documents/Data_sheets/Adhesives_and_Core/Honeycomb_core/Nomex-Honeycomb-Core-Aerospace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 (https://www.toraytac.com/media/5527e573-2e72-4aa4-bda7-5a49a20fef06/guunTA/TAC/Documents/Data_sheets/Adhesives_and_Core/Honeycomb_core/Nomex-Honeycomb-Core-Ae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)
13. https://compositeenvisions.com/document/resin-selection/
14. https://exelcomposites.com/guide-to-composites/resin-choices/
15. https://fiberglasswarehouse.com/blogs/news/ultimate-fiberglass-and-resin-guidebook-for-beginners (https://fiberglasswarehouse.com/blogs/news/ultimate-fiberglass-and-resin-guidebook-for-beginners)
16. https://smartechonline.com/resources/blog/vacuum-bagging-advantages/
17. https://www.addcomposites.com/post/what-is-automated-fibre-placement-afp
18. https://www.bpf.co.uk/plastipedia/processes/Resin_Transfer_Molding.aspx
19. https://hawthorncomposites.com/portfolio/switching-from-carbon-fiber-prepreg-to-resin-transfer-molding (https://hawthorncomposites.com/portfolio/switching-from-carbon-fiber-prepreg-to-resin-transfer-molding/)
20. https://incomepultrusion.com/filament-winding-an-in-depth-look/
21. https://www.addcomposites.com/post/filament-winding
22. https://www.scottbader.com/knowledge-hub/composites/hand-layup/?sb_analytics_cookies=accept (https://www.scottbader.com/knowledge-hub/composites/hand-lay-up/?sb_analytics_cookies=accept)
23. https://smartechonline.com/resources/blog/vacuum-bagging-advantages/
24. https://www.bpf.co.uk/plastipedia/processes/Resin_Transfer_Molding.aspx
25. https://hawthorncomposites.com/portfolio/switching-from-carbon-fiber-prepreg-to-resin-transfer-molding/ (https://hawthorncomposites.com/portfolio/switching-from-carbon-fiber-prepreg-to-resin-transfer-molding/)

26. https://scholarcommons.sc.edu/cgi/viewcontent.cgi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 (https://scholarcommons.sc.edu/cgi/viewcontent.cgi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)
27. https://incomepultrusion.com/filament-winding-an-in-depth-look/
28. https://ntrs.nasa.gov/api/citations/19880004775/downloads/19880004775.pdf
29. https://www.jiudingmaterial.com/news/the-advantages-and-disadvantages-of-hand-layup/ (https://www.jiudingmaterial.com/news/the-advantages-and-disadvantages-of-hand-lay-up/)
30. https://prototaluk.com/blog/additive-manufacturing-advantages-and-disadvantages/
31. https://www.learnleansigma.com/guides/decision-matrix-analysis/
32. https://www.nitprocomposites.com/blog/what-is-vacuum-bagging-process
33. https://acpcomposites.com/category/vacuum-bagging
34. https://www.fibreglast.com/blogs/learning-center/vacuum-bagging-equipment-techniques-for-room-temp-applications (https://www.fibreglast.com/blogs/learning-center/vacuum-bagging-equipment-techniques-for-room-temp-applications)
35. https://smartechonline.com/resources/blog/vacuum-bagging-advantages/
36. https://www.compositesworld.com/articles/avoiding-the-pitfalls-of-vacuum-infusion-processing (https://www.compositesworld.com/articles/avoiding-the-pitfalls-of-vacuum-infusion-processing)
37. https://incomepultrusion.com/vacuum-infusion-a-comprehensive-guide/
38. https://smartechonline.com/resources/blog/vacuum-bagging-advantages/
39. https://www.compositesworld.com/articles/avoiding-the-pitfalls-of-vacuum-infusion-processing (https://www.compositesworld.com/articles/avoiding-the-pitfalls-of-vacuum-infusion-processing)
40. Kassapoglou, C., “Minimum Cost and Weight Design of Fuselage Frames Part A: Design Constraints and Manufacturing Process Characteristics.”
41. Caminero, M. A., Rodríguez, G. P., and Muñoz, V., “Effect of Stacking Sequence on Charpy Impact and Flexural Damage Behavior of Composite Laminates,” Composite Structures, Vol. 136, 2016, pp. 345–357. https://doi.org/10.1016/j.compstruct.2015.10.019
42. Vasudevan, A., Pandiyarajan, R., Navin Kumar, B., and Vijayarangam, J., “Effect of Kevlar Ply Orientation on Mechanical Characterization of Kevlar-Glass Fiber Laminated Composites,” Vol. 988, 2020. https://doi.org/10.1088/1757-899X/988/1/012088
43. Mujahid, Y., Sallih, N., Mustapha, M., Abdullah, M. Z., & Mustapha, F. (2020). Effects of processing parameters for vacuum-bagging-only method on shape conformation of laminated composites. Processes, 8(9). https://doi.org/10.3390/PR8091147
44. Xiujie Zhu, Chao Xiong, Junhui Yin, Huanran Zhou, Huiyong Deng, Youchun Zou,
Bending responses of CFRP thin-walled tubes with different sectional shapes: Experimental, analytical and numerical investigation, Composite Structures, Volume 304, Part 1, 2023, 116374, ISSN 0263-8223, https://doi.org/10.1016/j.compstruct.2022.116374.
45. Lamination Parameters for Sandwich and Hybrid Material Composites, (https://arc.aiaa.org/doi/abs/10.2514/1.J059093) Gustavo H. C.
Silva and Yasser Meddaikar, AIAA Journal 2020 58:10, 4604-4611
46. Harris, Charles & Shuart, M. & Starnes, James. (2002). Design and Manufacturing of Aerospace Composite Structures, State-of-the-Art Assessment. Journal of Aircraft - J AIRCRAFT. 39. 545-560. 10.2514/2.2992.
47. Parveez, Bisma & Kittur, Mohammed Ibrahim & Badruddin, Irfan & Kamangar, Sarfaraz & Hussien, Mohamed & Umarfarooq, M A. (2022). Scientific Advancements in Composite Materials for Aircraft Applications: A Review. Polymers. 14. 5007. 10.3390/polym14225007.

48. Kaufman, Brett & Briant, Clyde. (2018). Metallurgical Design and Industry Prehistory to the Space Age: Prehistory to the Space Age. 10.1007/978-3-319-93755-7, Page 285
49. https://ntrs.nasa.gov/api/citations/19970017924/downloads/19970017924.pdf, Accessed 27/03/2025

## APPENDIX

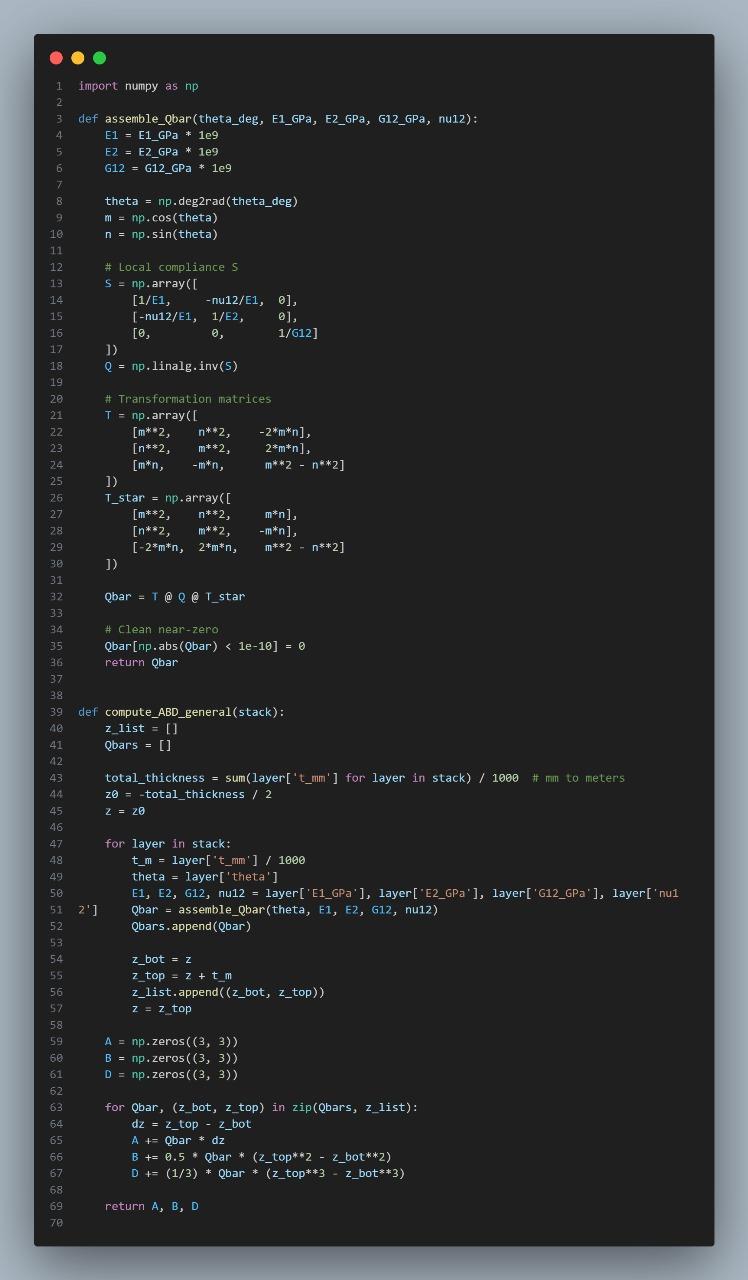
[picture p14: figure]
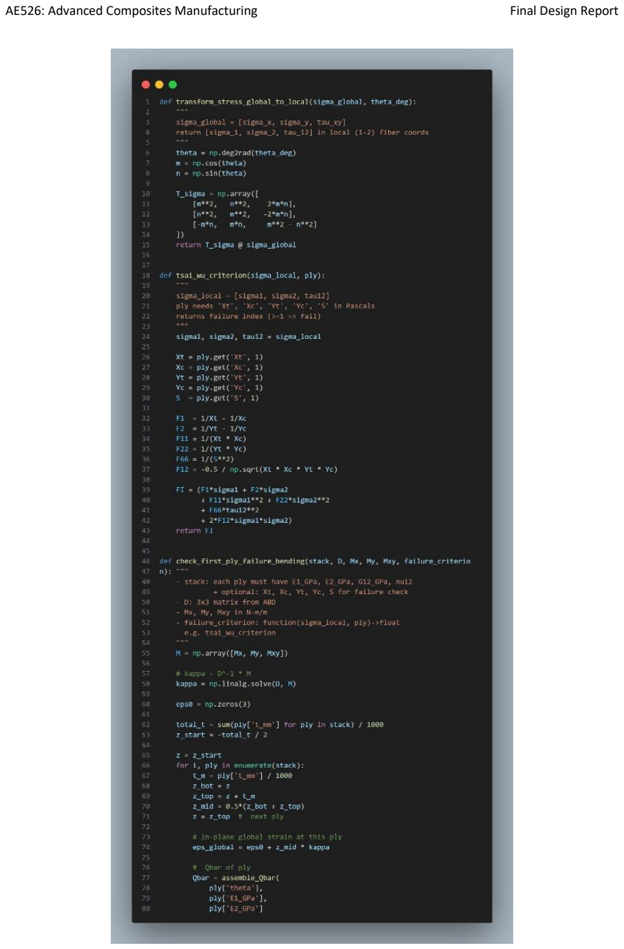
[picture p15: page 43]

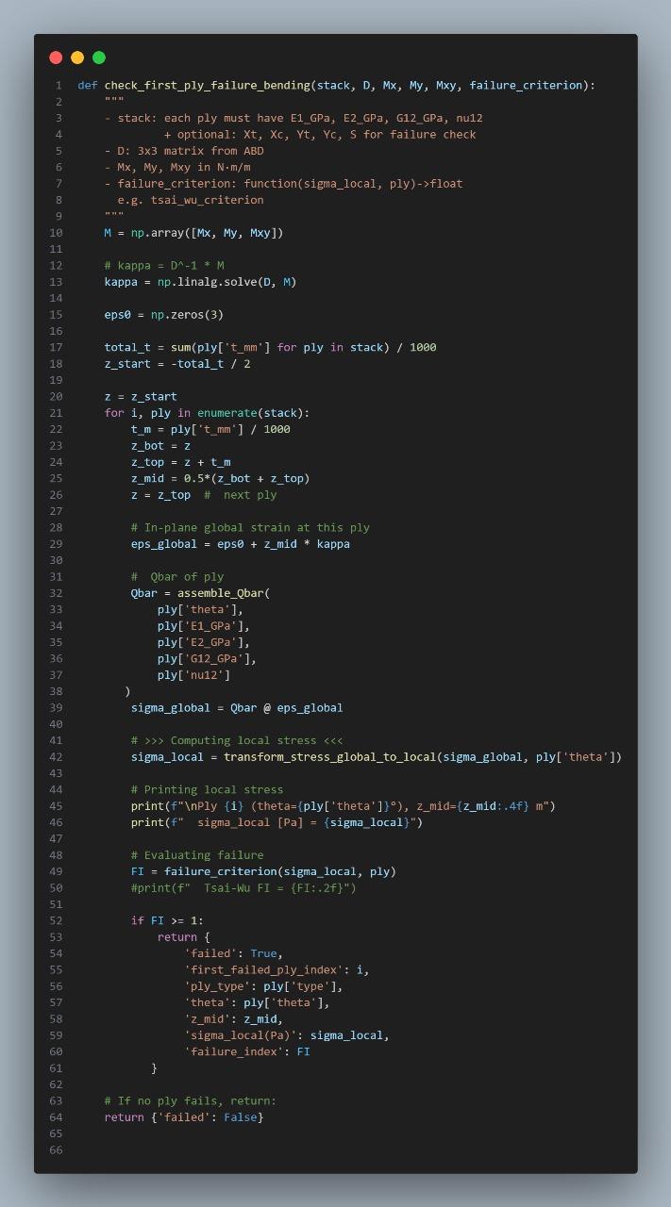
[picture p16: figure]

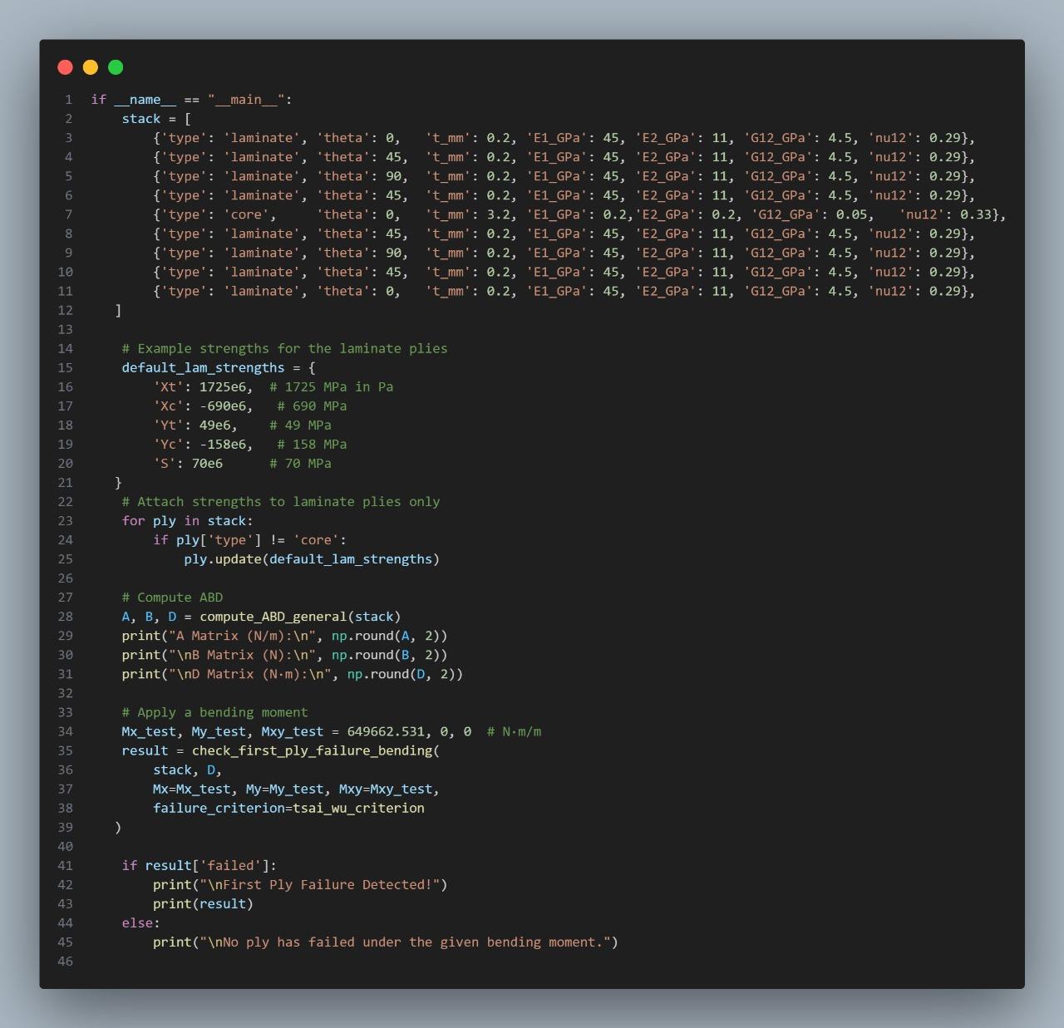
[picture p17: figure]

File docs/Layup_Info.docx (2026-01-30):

## 4.

## 4.1. Recommended Number of Composite Layers for Bending Stiffness & Minimum Weight

- Minimum Required Layers:
  - 3-ply layup (~0.53 mm thickness) was identified as the minimum requirement to prevent porosity and moisture intrusion.[8]
  - Hybrid CFRP-GFRP composite laminates were found to be 17% lighter while maintaining stiffness.
- Optimal Layer Count for Stiffness vs. Weight Trade-off:
  - 36–40 layers were recommended for fuselage structures under bending and impact loads.
  - Unidirectional laminates with [0]12 performed best in flexural strength but were prone to brittle failure.[9]
- Impact on Performance & Cost:
  - DD layup ([±30°/90°/0°/±75°]) provided higher torsional stiffness and weight efficiency than traditional stacking sequences.
  - Multi-objective optimization showed that minimizing layers reduced weight, but at the cost of lower impact resistance.[10]

### Comparison Across Papers:

Study | Optimal Layer Count | Weight Savings | Comments
Minimum Cost & Weight Design | 3-ply min | Moderate | Manufacturing constraints require a minimum of 3 plies
Optimal Layup Selection | 36-40 layers | High | DD layups outperformed traditional sequences
Kevlar-Glass Fiber Laminates | 6 layers | Moderate | Kevlar improved impact resistance but didn’t enhance stiffness
Stacking-Sequence Design | Computed via optimization | High | Symmetric stacking reduced stress concentrations
Numerical Optimization | Hybrid CFRP-GFRP | 17% weight reduction | Reduced weight while maintaining impact tolerance

## 4.2. Relation Between the Number of Layers & Fuselage Stiffness Under Bending

- Thicker laminates increase bending stiffness, but excessive layers lead to stress concentrations and premature delamination.[8]
- Hybrid laminates provided a 17% weight reduction while maintaining stiffness, making them ideal for aerospace fuselages.
- Pareto frontier optimization showed that fewer layers improve cost-effectiveness but reduce flexural resistance.
- Shear failures were observed in unidirectional laminates ([0]12), emphasizing the need for multidirectional layups.[9]

### Comparison Across Papers:

Study | Effect of More Layers | Key Findings
Minimum Cost & Weight Design | Stiffness ↑, Stress ↑ | More layers increase stiffness but require symmetric stacking to avoid stress concentrations
Optimal Layup Selection | Stiffness ↑, Weight ↑ | Balanced laminates offer the best trade-off between stiffness and weight
Kevlar-Glass Fiber Laminates | Stiffness ~ | Kevlar improved toughness but had minimal effect on bending stiffness
Stacking-Sequence Design | Stiffness ↑ | Gradual ply transitions improve stiffness while reducing stress concentrations
Numerical Optimization | Stiffness ↑ | Weight-efficient hybrid laminates showed better performance than CFRP-only laminates

## 4.3. Optimal Fiber Orientation for Cylindrical Composite Fuselage Under 3-Point Bending

- Best Ply Orientations for Bending:
  - 0° plies improved axial stiffness but increased delamination risk.
  - ±45° plies significantly improved impact absorption and shear strength.[9]
  - 90° plies enhanced lateral stability but contributed minimally to bending stiffness.[10]
- Key Findings by Orientation:
  - 0° Unidirectional Laminates ([0]12) → High stiffness but brittle failure.
  - ±45° Laminates ([±45]3s) → Best impact absorption and damage tolerance.
  - Multidirectional Laminates ([0/90/(±45)2s]) → Best balance between impact resistance and bending stiffness.

### Comparison Across Papers:

Ply Orientation | Best For | Study
0° (Axial Load-Bearing) | Maximum stiffness, but brittle failure | Stacking-Sequence Design
±45° (Shear Strength & Energy Absorption) | Best for impact and fatigue resistance | Effect of Stacking Sequence
90° (Transverse Stability) | Improves lateral stability, but limited bending stiffness | Kevlar-Glass Hybrid Study
DD Layup ([±30°/90°/0°/±75°]) | Best torsional stiffness & weight efficiency | Optimal Layup Selection

## 4.4. Recommendations on Symmetric & Balanced Layups for Stress Reduction & Delamination Prevention

- Symmetric and balanced laminates ([0°/±45°/90°]2s) provided the best damage resistance and weight optimization.
- Multidirectional layups improved energy absorption, making them ideal for fuselage cutouts and areas prone to stress concentration.
- Hybrid CFRP-GFRP laminates reduced interlaminar stress while maintaining bending stiffness.

Optimization Plan for SAMPE Fuselage Layup

Step 1: Define Objectives

1. Maximize bending stiffness to minimize deflection under a 1,000 lbf load.
2. Minimize interlaminar shear stress to prevent delamination around cutouts.
3. Optimize weight while maintaining structural integrity.

Step 2: Constraints

1. Symmetry: Ensure symmetric stacking sequence to avoid warping.
2. Balance: Include equal numbers of +45° and -45° plies for torsional stability.
3. Minimum Ply Count: At least three plies per orientation (0°, ±45°, 90°).

Step 3: Candidate Layup Configurations

Layup Configuration | Description | Expected Performance
[0/90/(±45)₂s] | Symmetric, balanced multidirectional layup | Best balance between bending stiffness, shear strength, and damage tolerance.
[±45/0]₆ | Double-biaxial angle layup | High shear strength but reduced axial stiffness compared to multidirectional layups.
₁₂ | Unidirectional layup | High axial stiffness but prone to brittle failure under transverse loads.

Step 4: Evaluate Performance Using Classical Lamination Theory (CLT)

1. Calculate laminate stiffness matrix (DD) for each configuration:

D=112∑k=1nQk⋅(zk3−zk−13)D=121k=1∑nQk⋅(zk3−zk−13)

Where QkQk is the transformed reduced stiffness matrix for each ply orientation.

2. Analyze shear stress distribution under applied loads:

τxy=VA+stress concentration factors near cutoutsτxy=AV+stress concentration factors near cutouts

3. Use Tsai-Wu failure criterion to predict failure modes:

F1σx+F2σy+F11σx2+F22σy2+F12σxσy+F66τxy2=1F1σx+F2σy+F11σx2+F22σy2+F12σxσy+F66τxy2=1

Step 5: Perform Multi-Objective Optimization

Use optimization software (e.g., MATLAB or ANSYS):

1. Define objectives:
  - Maximize D11D11 (axial stiffness).
  - Minimize peak shear stress (τxyτxy).
  - Minimize weight (ttotalttotal).
2. Apply constraints:
  - Symmetry and balance.
  - Minimum ply count per orientation.
3. Run optimization algorithms:
  - Genetic Algorithm (GA): Explore global optima for stacking sequences.
  - Branch-and-Bound: Efficiently refine stacking sequences within manufacturing constraints.

Final Deliverable

Once optimized, validate the selected layup using Finite Element Analysis (FEA) to confirm:

1. Compliance with SAMPE load-deflection requirements (≤≤1" deflection under 1,000 lbf).
2. Reduced shear stress concentrations around cutouts.

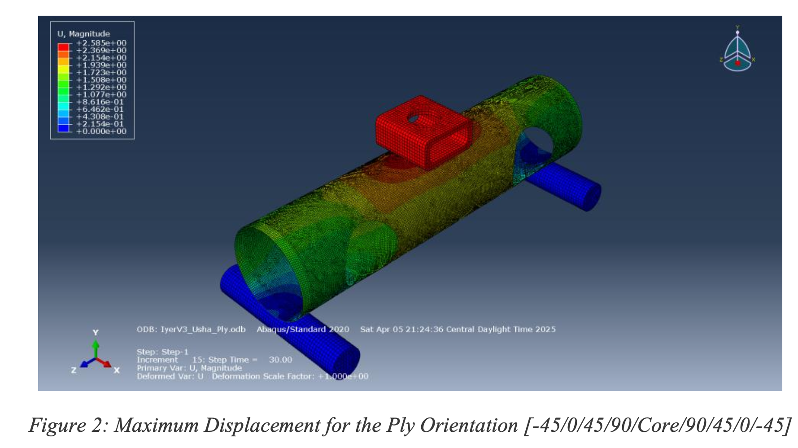
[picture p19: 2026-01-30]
images/abaqus_displacement.png

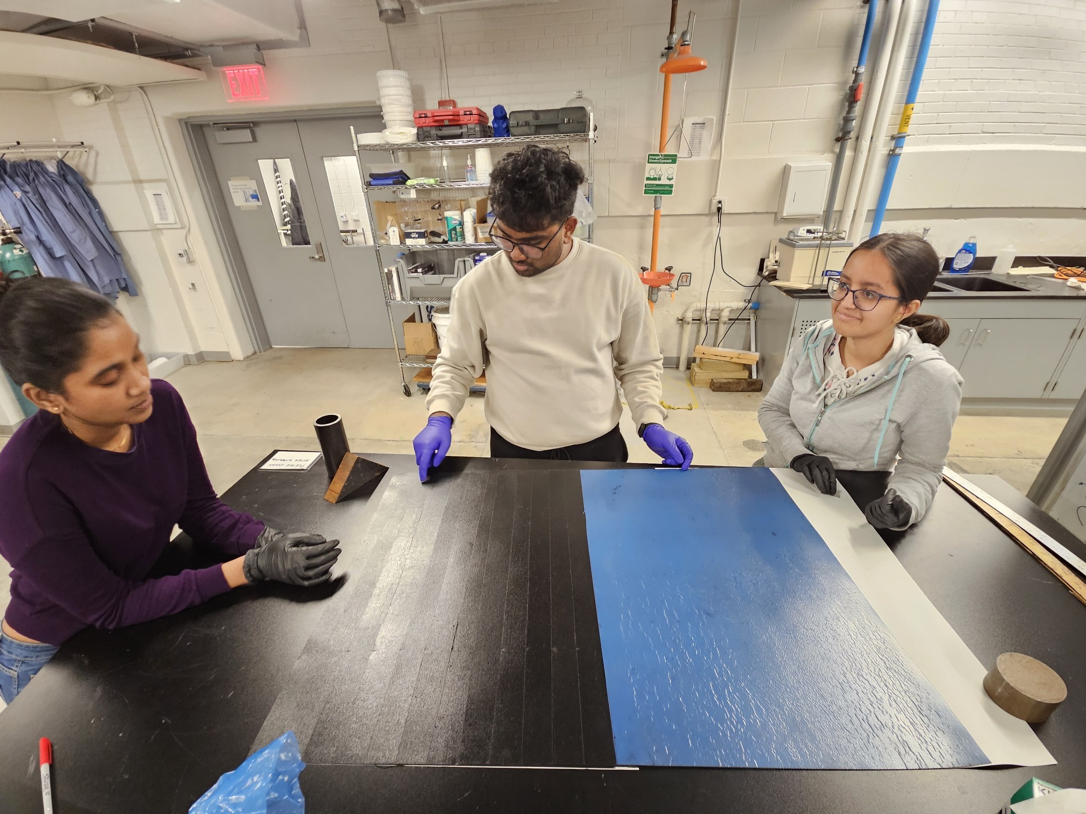
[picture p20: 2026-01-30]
images/layup_team.jpg

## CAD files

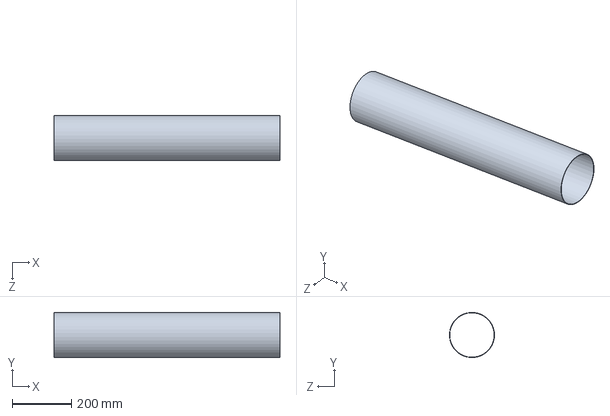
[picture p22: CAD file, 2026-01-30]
cad/fuselage_1.SLDPRT
762.0 x 152.3 x 152.2 mm

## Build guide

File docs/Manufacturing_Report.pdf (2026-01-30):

## MANUFACTURING REPORT: FUSELAGE

Following the design report, the manufacturing report aims to present a comprehensive study and review of the manufacturing methods considered to produce the fuselage structure. Various manufacturing techniques were analyzed based on their merits and demerits. After a detailed discussion, it was concluded that vacuum bagging with the E-Glass prepreg followed by autoclave curing was selected as the primary manufacturing process. This was due to its superior process control, final laminate quality and adherence to the SAMPE 2025 guidelines. The report outlines a detailed manufacturing methodology, risk assessment, alternate manufacturing plans (if necessary) and finishing techniques employed to ensure that the final product complies with satisfactory quality and manufacturing standards and is optimized for performance and manufacturability.

### 1. Materials

Prepregs are formations of resin and fibers preform with enhancement in the ease of handling without any requirements of further treatments other than the curing cycles, hence acting as precursors to manufacture composites used in a high-performance setting. Prepregs have a characteristic of providing desirable tack and drape to allow the formation of structures with complicated shapes. Prepregs based on thermosetting matrices are generally formed when the fiber tow is impregnated with the resin under elevated temperatures and pressure, further quenched and stored in a cool condition so as not to initiate the reaction(curing) mechanism. [1]

Prepregs are significant in manufacturing high-performance, high-stress, enduring composites [2]. Prepregs are mostly selected because of their ability to form void-free composite structures, which could be manufactured in a rapid process, and which would help in reducing the constraints of handling and the possibility of varied accumulation of resin (in case of resin infusion technique). Therefore, for the manufacturing of a fuselage, which is idealized as a cylinder, using a prepreg is the best choice to achieve high structural durability as well as maintain geometrical characteristics [3].

Since the SAMPE bending test requires a continuous loading condition until the cylinder breaks, the plies undergo tension in the bottom but compression at the top; therefore, it is imperative to look at the properties of the fibers due to fibers being the maximum load-bearing constituent in the axial direction. The table below shows the superior properties of S-Glass which offers several distinct benefits over E-Glass for aerospace applications. Its 5.2% elongation, compared to E-Glass’s 4.7%, improves impact resistance in multidirectional laminates, while its higher fiber toughness reduces the risk of delamination during manufacturing. Additionally, its 30% greater compressive strength contributes to enhanced structural integrity around door openings and other high-stress areas.

Property | S-Glass | E-Glass
Tensile Strength | 4600 MPa | 3400 MPa
Elastic Modulus | 89 Gpa | 72 Gpa
Density | 2.53 g/cm³ | 2.54 g/cm³
Impact Resistance | High | Moderate
Table 1: Properties of Different types of glass fibers

Within prepregs, the choice of fiber matrix system for the prepreg, which also adheres to the regulations of the SAMPE design competition, brings down the choice of fiber to glass fibers. Ideally, S glass fibers with epoxy resin system would have been the optimum choice as the S-glass fiber composites have high stiffness modulus which is required to withstand the 1000 lbf load and less than 1” deflection. But the ABAQUS simulation as seen from the figure below shows a respectable deflection of less than 0.5” in case of E-glass fiber which has modest modulus as compared to S-glass fiber allowing for room adjustment without taking a cost penalty. The ABAQUS calculations in the design report had been done using the effective Young’s modulus of the composite, wherein the resin system was opted as epoxy-based and the fiber as the S/E glass fiber.

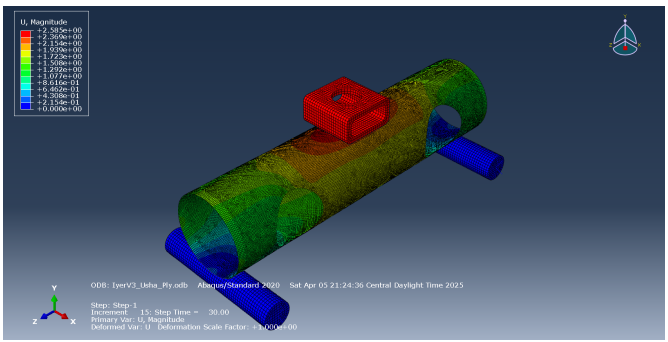
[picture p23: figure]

Fig 1: ABAQUS simulation of E-glass fiber composite with cutouts.

Essentially, E glass fibers with epoxy-based resin system are the optimum choice of fiber system because of their lower cost with favorable mechanical properties, as glass fibers have high tensile strength, good impact resistance and ease of processing.

Finally, it is also imperative to discuss the type of weave required for the composite over general unidirectional prepregs. In all the hand calculations and ABAQUS simulations, the composite properties considered are unidirectional, and we had done an optimization study of prepreg orientation using the unidirectional properties.

Unidirectional prepregs are the best candidates for composites which are loaded ideally in the axial direction in case of high tensile strength and stress applications, but since the bending loading conditions are a mixture of tensile stress as well as shear stresses, which adds to the material’s resistance to the bending load additionally, due to the cut outs there are stress concentrations which would need to be accounted for and these kinds of complex stress accumulations is best utilized for the woven prepregs wherein a single ply can withstand stresses in multiple directions (warp and weft) with fiber being dominant in both the directions hence providing higher stress and strength capabilities for the final products. Finally, as we are moving forward with a woven prepreg, the type of woven prepreg is also under consideration. The following table shows the advantages and disadvantages of various types of weaves:

Weave Type | Advantages | Disadvantages
Plain Weave | Stable and easy to handle | Poor drapability, high crimp
Twill Weave | High drapability and better strength | Prone to fraying
Satin Weave | Best Drapability and high strength | Low stability
Basket Weave | High strength and impact resistance | Bulky and less stable

Table 2: Various types of weaves with their advantages and disadvantages.

The ease of handling, lead time, and manufacturing cost are the main considerations. Two plain weave prepregs were considered: easy to handle, stable with a lower lead time, and providing the same strength as unidirectional ply. The plain weave offers fiber-dominated strength in both transverse and longitudinal directions, aiding in shear and bending stress. The Prepreg - Fiberglass Woven (7781 E-Glass) - 39.37” Wide x 36” Long x 0.010” Thick - 32% Resin Content w/Black pigment (461 gsm OAW) - 250F Resin is the better choice due to its superior tensile strength and modulus, as discussed above. The mechanical properties of the two prepregs are given below:

Prepreg | Prepreg - Fiberglass Woven (7781 E-Glass) - 39.37" Wide x 36" Long x 0.010" Thick - 32% Resin Content w/Black pigment (461 gsm OAW) - 250F Resin | Prepreg - Fiberglass Woven (120 Glass) Epoxy (Newport 301) -38" Wide x 0.005" Thick - 40% Resin Content w/out pigment (185 gsm OAW)
Prepreg Overall Weight | 440 GSM | 185 GSM
Resin Content | 32% | 40%
Resin System | Propreg 250F | Newport 301
Tensile Modulus | 10.5 msi | 2.96 msi
Tensile Strength | 285 ksi | 55.5 ksi
Weight | 45812.79 g | 13154.168 g
Table 3: Properties of E-glass and epoxy resin prepreg systems.

Core materials play a crucial role in sandwich composite structures, providing a lightweight means of achieving the required strength, stiffness, and energy absorption. When developing high-performance sandwich structures, engineers commonly use materials like aluminum honeycomb cores due to their strength-to-weight ratio and cost-effectiveness. Polymer foam cores such as polymethacrylimide (PMI) foams are also frequently chosen for applications requiring superior mechanical properties, however, the current guidelines constraints limit the choice to Nomex and Kevlar honeycomb cores. Hence are studied further to optimize the fuselage structure effectively. Nomex and Kevlar honeycomb cores are frequently utilized in aerospace applications due to their favorable strength-to-weight ratios, fire resistance, and durability. Each variant presents distinct advantages and limitations, making a detailed comparison essential to identify the most suitable material for specific fuselage sections. Based on the comparative analysis above, Nomex honeycomb cores are well suited for cost-sensitive applications demanding moderate strength and stiffness, making them ideal for fuselage components such as cabin floors and bulkheads. Kevlar honeycomb cores, in contrast, are more appropriate for high-stress regions requiring maximum shear strength and superior compressive performance. Strategic allocation of these materials ensures optimized structural efficiency and performance while complying with relevant design and material constraints

### 2. Manufacturing Methodology:

Manufacturing of a high-performance composite could be done using various procedures. The methodology selected for this report is the one that has high structural integrity, cost-effectiveness, design and process flexibility.

Vacuum Bagging:

The vacuum bagging process involves sealing layers of fiber under a vacuum bag to ensure uniform pressure during curing. This technique is designed to consolidate the laminate effectively while simultaneously removing excess resin and trapped air. By creating a controlled environment under vacuum pressure, the fibers are compressed uniformly, resulting in a more compact and cohesive structure. The vacuum bag acts as a barrier, maintaining consistent pressure throughout the curing process, which is critical for achieving optimal laminate quality. Vacuum bagging offers several advantages over traditional hand layup methods. One of its key benefits is improved consolidation, which leads to reduced void content within the laminate. This results in a stronger and more durable composite structure. Additionally, vacuum bagging provides more consistent thickness across the laminate compared to hand layup techniques, ensuring uniformity in structural properties. The method also delivers higher strength-to-weight ratios and more consistent quality, making it particularly beneficial for medium-sized fuselage structures. However, there are some disadvantages associated with this process. Vacuum bagging requires additional equipment such as vacuum pumps and bagging film, which can increase costs slightly compared to hand layup methods. Furthermore, operator proficiency is essential to prevent leaks during the process, as the maximum pressure achievable is limited to atmospheric pressure (approximately 14.7 psi). Vacuum bagging is commonly employed for primary fuselage structures where moderate strength and weight efficiency are essential. Its ability to produce consistent and high-quality laminates makes it an ideal choice for applications requiring reliable performance in medium-sized composite components. While it may not be suitable for all manufacturing scenarios due to its equipment requirements and cost considerations, vacuum bagging remains a preferred method for achieving structural integrity in aerospace applications where strength-to-weight ratios are critical.

Additive Manufacturing (3d Printing):

Additive manufacturing, commonly referred to as 3d printing, is a process in which composite materials, such as carbon fiber-reinforced thermoplastics, are deposited layer by layer to construct parts. This technique eliminates the need for extensive tooling and allows for the precise fabrication of components directly from digital designs. By building parts incrementally, additive manufacturing offers a highly controlled and efficient method for producing composite structures while minimizing material waste. The advantages of additive manufacturing are significant, particularly in terms of design flexibility. This method enables the creation of intricate geometries and integrated features that would be challenging or impossible to achieve with traditional composite fabrication techniques. Additionally, additive manufacturing excels in rapid prototyping, allowing engineers to quickly test and iterate designs with minimal material waste. Despite these benefits, there are notable disadvantages. The mechanical properties of parts produced through additive manufacturing may be inferior to those achieved using conventional composite methods. Furthermore, this process is generally restricted to smaller scale parts and offers limited material options compared to traditional techniques. Additive manufacturing is particularly suited for prototyping fuselage components that require complex internal structures or lightweight core designs. Its ability to produce intricate geometries and lightweight parts makes it ideal for applications where design complexity and efficiency are prioritized. While it may not be suitable for large-scale production or high-performance structural components due to its limitations in mechanical properties and material selection, additive manufacturing remains a valuable tool for innovation in aerospace prototyping and lightweight design [9].

Resin Transfer Molding (RTM):

Resin Transfer Molding (RTM) is a composite manufacturing process that involves positioning dry fibers within a closed mold and injecting resin under pressure to impregnate the reinforcement thoroughly. The resin, often combined with catalysts, flows into the mold cavity to saturate the fiber preform, ensuring uniform distribution and complete impregnation. Once the resin cures, the mold is opened, and the finished component is removed. RTM enables precise control over fiber orientation and resin content, making it suitable for producing high-performance composite parts with excellent dimensional accuracy and surface finishes. This process is widely used in industries such as aerospace, where lightweight and durable components are essential. RTM offers several advantages that make it a preferred method for composite manufacturing. It produces high-quality parts with consistent dimensions and excellent surface finishes on both sides of the component. The process is particularly well-suited to complex geometries and integrated features, such as door cutouts, due to its ability to mold intricate shapes with tight tolerances. Additionally, RTM minimizes material waste by allowing near-net-shape production, reducing post-processing requirements. However, there are some disadvantages associated with RTM. The initial setup cost is high due to the need for specialized mold fabrication, which can be a barrier for small-scale production or prototyping. Moreover, achieving optimal results requires careful control of processing parameters and skilled operators. RTM is ideal for manufacturing high-performance fuselage sections that demand tight tolerances and reduced post-processing. Its ability to produce lightweight yet durable components make it particularly valuable in aerospace applications where structural integrity and weight optimization are critical. While its high initial costs may limit its use in certain scenarios, RTM remains indispensable for applications requiring precision-engineered composite parts with complex geometries and superior mechanical properties [5].

Filament Winding Filament winding is a composite manufacturing technique that involves winding continuous fibers, such as carbon, glass, or aramid, onto a rotating mandrel. The fibers are impregnated with resin either before or during the winding process to ensure proper bonding and structural integrity. The mandrel rotates while a carriage system moves horizontally, laying down the fibers in predetermined patterns to achieve the desired orientation and thickness. Once the winding is complete, the resin is cured using heat or other methods, and the mandrel is removed to leave behind a hollow composite structure. This process is particularly effective for creating cylindrical or spherical components with high mechanical strength and precision. Filament winding offers several advantages, making it an efficient and reliable method for composite manufacturing. It provides high hoop strength due to its ability to optimize fiber placement for cylindrical shapes, making it ideal for pressure vessels or structures subjected to hoop loading. The process efficiently utilizes continuous fibers, resulting in strong and lightweight components with minimal material waste. Additionally, filament winding is highly automated, ensuring repeatable quality and reducing labor costs. However, there are limitations to this method. It is primarily restricted to axisymmetric geometries and cannot accommodate complex shapes with openings, such as fuselage sections with integrated features. Furthermore, filament winding requires specialized equipment, which can be costly to acquire and operate. Filament winding is particularly suitable for manufacturing fuselage tubes or pressure vessels that demand significant hoop strength and relatively simple geometries. Its ability to produce lightweight yet durable components make it an excellent choice for applications where internal pressure resistance is critical. While its geometric constraints limit its use for more intricate designs, filament winding remains a preferred method for producing high-performance cylindrical structures in industries such as aerospace, automotive, and industrial manufacturing [5].

Method | Cost (4) | Manufact uring Time (4) | Quality (5) | Impleme ntation (4) | Flexibility (4) | Compliance (5) | Total Weighted Score
Hand Layup | 5 | 2 | 2 | 5 | 2 | 5 | 91
Vacuum Bagging | 4 | 3 | 4 | 4 | 3 | 5 | 105
RTM | 2 | 4 | 4 | 2 | 4 | 4 | 88
Automated Fiber Placement | 1 | 5 | 5 | 1 | 5 | 4 | 93
Filament Winding | 3 | 3 | 4 | 3 | 2 | 5 | 89
Additive Manufacturing | 2 | 4 | 4 | 3 | 5 | 5 | 101

Table 4: Decision Matrix for various manufacturing types.

Conclusion

Based on the outcomes of the comprehensive decision matrix, vacuum bagging is identified as the most suitable manufacturing method for composite fuselage production. This technique offers an optimal balance of cost efficiency, manufacturing quality, and ease of implementation, aligning well with the rigorous performance requirements of the fuselage. Although additive manufacturing presents significant potential for producing complex geometry and innovative designs, its current limitations in scalability and mechanical performance render it less practical for mid-scale fuselage fabrication. The established reliability of vacuum bagging, along with its capacity to deliver consistent and high-quality results, reinforces its selection as the preferred method for manufacturing high-performance composite fuselages. Additionally, along with the decision matrix, the constraint of manufacturing needs to be considered as well, which allows two types of processes, i.e. resin infusion with dry fabric and vacuum bagging of the prepreg. The vacuum bagging with prepregs proves to provide better handling. It also avoids the chances of more accumulation of resin possible in the resin infusion case and works as a faster turnaround cycle for the wherein multiple curing is required since we need to use layers of prepregs and honeycomb structure as well which in the multiple curing cycle of prepreg vacuum bag process would be able to be bonded perfectly well. Additionally, vacuum bagging of prepregs would provide the extra pressure during the autoclave procedure required to make a sturdier material

### 2.1 Manufacturing Process Summary: Vacuum Bagging and Autoclave

Curing of E-Glass Prepreg for Cylindrical Cross-section

For the fabrication of the fuselage structure, the team selected vacuum bagging using E-glass
prepreg | followed | by | autoclave | curing | as | the | manufacturing | process.
Between the two available processes in the Composites Manufacturing lab — resin infusion using dry fabric and vacuum bagging using prepreg — vacuum bagging with prepreg was chosen to ensure greater process control, part quality, and compliance with competition manufacturing standards.

Several critical factors influenced this decision:

- Equipment Availability:
The laboratory provides access to a vacuum bagging setup and an operational autoclave, enabling high-pressure, high-temperature curing. This enables manufacturing of high-quality composite parts by combining vacuum compaction with high-pressure, controlled temperature autoclave curing, resulting in improved laminate consolidation, minimized void content, and increased fiber volume fraction.
- Process | Manageability | and | Quality | Control:
Although the team has limited prior experience with both vacuum bagging and resin infusion, vacuum bagging of prepreg materials was deemed more manageable due to the
inherent | stability | of | prepregs.
Prepreg materials offer highly controlled resin content and uniform fiber alignment,
significantly | reducing | variability | compared | to | resin | infusion | methods.
This results in improved control over fiber alignment, reduced risk of dry spots or resin-rich zones, and ensures consistent laminate thickness. Which factors into improving the
laminate | quality | compared | to | resin | infusion | processes.
- Manufacturing | Simplicity | and | Risk | Reduction:
Vacuum bagging prepreg reduces the number of variables involved in the fabrication process (such as infusion pressures, flow media setup, resin pot life, and mold sealing quality), which in turn lowers the likelihood of manufacturing defects. It is especially advantageous when working with curved or cylindrical structures like the fuselage, where maintaining uniform resin flow in an infusion process could be challenging.

Prepreg layup eliminates the risk of dry spots, uneven resin distribution, and complex
infusion | troubleshooting.

- Surface | Finish | and | Dimensional | Accuracy:
The combination of vacuum bagging and autoclave curing allows for excellent surface finish quality and precise dimensional control, reducing the need for extensive post-processing and ensuring better geometric tolerance. Autoclave-cured prepreg parts achieve superior surface finishes and require minimal post-processing. This reduces sanding, filling, and cosmetic repair work after curing — important for maintaining structural integrity and saving manufacturing time.
- Compatibility with Fuselage Design:

Vacuum bagging and autoclave curing are well-suited for cylindrical structures, where uniform pressure application is critical to avoid wrinkles, fiber distortion, and dimensional deviations. This method aligns with the manufacturing assumptions made during the fuselage design optimization process.

- Material | Availability | and | Sourcing | Constraints:
While the initial plan considered using S-glass braided sleeves with vacuum-assisted resin transfer molding (VARTM), difficulties in sourcing appropriately sized braided sleeves (5.5-inch inner diameter) made this approach impractical.

Transitioning to woven E-glass prepreg ensures material availability, while still meeting design stiffness and strength targets.

- Alignment | with | Design | Report | Findings:
Vacuum bagging and autoclave curing were identified as the most viable manufacturing approach during the design phase, based on a thorough review of literature, industry best practices for fuselage manufacturing, and feasibility analysis of various composite manufacturing methods.

The intended fuselage design features a cylindrical cross-section, with the following dimensions optimized through engineering design calculations:

- Inner Diameter: 5.5 inches
- Outer Diameter: 6 inches
- Length: | | 24 | | inches

Material Selection:

- Reinforcement: Woven E-glass prepreg (14086)
- Curing Method: Vacuum bagging of prepreg followed by autoclave curing (pressure-
assisted | high-temperature | cure).

This approach ensures the production of a structurally sound, competition-compliant fuselage structure with high mechanical performance, minimal void content, and superior surface quality.

### 2.2 Alternate Manufacturing Approach: Rolled Tube Method with Oven

Curing

In case vacuum bagging and autoclave curing cannot be successfully completed, the team has identified an alternate manufacturing approach to ensure that fabrication of the fuselage structure can still proceed.

The alternate method would involve the rolled tube technique, followed by oven curing. In this approach, woven E-glass prepreg would be manually wrapped around a polished aluminum mandrel in sequential layers according to the designed fiber orientation schedule. After layup, the laminate would be consolidated using high-temperature shrink tape, which applies
radial | pressure | during | the | oven | curing | process.
Curing would be performed in a conventional oven following the specified prepreg cure cycle After curing and cooling, the part would be demolded and trimmed as needed.

While this method provides a practical backup plan, it is acknowledged that it is not ideal for
fuselage | | | | | | manufacturing.
However, the rolled tube method offers several advantages that make it a reasonable alternate approach:
- Simplified Equipment Requirements
- Material Compatibility: The woven E-glass prepreg material can be used.
- Manufacturing Flexibility: Manual wrapping around a mandrel is less sensitive to vacuum bag sealing and leak issues compared to vacuum bagging large, curved molds.

In summary, although the rolled tube method would not produce an ideal aerospace-grade fuselage structure, it remains a viable alternate manufacturing method to ensure project completion if autoclave-based vacuum bagging cannot be executed.

### 2.3 Prepreg Handling

A prepreg is a composite material which has already been pre-impregnated with a resin system. They are a complex system of composite materials which must be handled very carefully. The current project uses a 14086-d-group E-Glass prepreg for use as the principal composite layup, along with a NOMEX core. Following are a few salient points which should be followed while handling prepreg systems:
1. Storage: When handling prepreg, it is very crucial to store it in the freezer to prevent the resin from curing completely. The prepreg was stored in a cold storage freezer where the temperature was maintained low enough to ensure that the curing process of the resin was arrested.
2. Defrosting: Before using the prepreg for manufacturing it is let to recover to room temperature on its own, without any external influence. This is to let the resin revert to a workable temperature. Manually influencing the procedure could result in condensation forming on the prepreg, affecting results. It is recommended that the prepreg be left out at least 20 hours at room temperature.
3. It is also important to note that every prepreg has a specific shelf-life corresponding to the storage conditions. Keeping the prepreg outside for a longer time proportionally reduces its shelf-life.

### 2.4 Preparation of the Composite Assembly for Curing

There are several steps which must be executed before the composite can be sent for its first cure.

2.4.1 Cutting

1. The Prepreg was rolled out from its stack, measured, and then cut using a rolling cutter. The measurement of the prepreg was based on hand calculations which computed the total length of the composite required per ply to wrap the entire mandrel, without any overlap.
2. Correspondingly, the breather and release film and the vacuum bag were cut as well.

2.4.2 Preparation of the Mandrel

The Mandrel is perhaps the most important component of the assembly process, as the prepreg plies and the core will be laid up on it. Considering that the mandrel is going to be cured along with the composite, it must be able to withstand high temperatures, as well as not expand much due to the heat being supplied to it. Therefore, the team decided to go with Aluminum as the choice of material for the mandrel. It has a small two-step process for preparation, which is listed below:
1. The Mandrel is first held upright. To remove any contaminants which might be present on the surface of the mandrel, it is first cleaned with acetone. The acetone is first applied on an applicator which may be a cloth or a paper towel, and this is then rubbed on the surface of the mandrel thoroughly.
2. Care must be taken to ensure that the Acetone is sprayed onto the applicator only and is not spilled anywhere else.
3. Post the acetone swab, the mandrel is treated with a chemical release agent. The chemical release agent available at the Composites Laboratory has its own swab, thus not requiring additional supplies of applicator.
4. The chemical release agent should be applied uniformly on the surface of the mandrel, and while applying, special care must be taken to ensure that it is applied in a single direction.
5. Allow some time for the agent to dry. Post drying, it is possible that the color of the application may change, and this can be considered as completely normal.
6. Note that the personnel operating with the chemical release agent should not breathe too much of it as it may contain harmful and poisonous fumes.

2.4.3 Fixture and Setting of the Mandrel

1. Ideally, the Mandrel should be laid on a fixture for the entire curing process. An illustration of the ideal fixture is shown here.
2. The two stands on either side are the main components which are responsible for handling the entire weight of the Mandrel and the Composite Assembly.
3. The Top Clamps are responsible for restricting any movement in the vertical direction and completely close the mandrel from either end, thus allowing only rotation of the mandrel.
4. There are extrusions on one end of the clamps,
which provides a holding area for the hand to

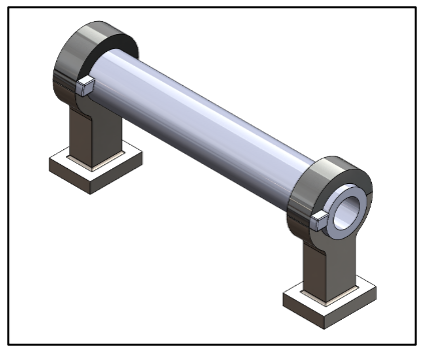
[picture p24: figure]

aid easier removal of the clamp from the fixture.
5. While a fixture should be able to restrict movement in all orientations, allowing rotation provides a very convenient way to apply the prepreg onto the surface of the prepared mandrel.
6. The fixture is set up on the autoclave stand, with the stands being placed at a set distance from each other.
7. The Mandrel is placed on the stand, ensuring that neither part is damaged while doing so. The studs for the clamps are set on the fixture.
8. The clamps are placed, closing off the mandrel and completing the fixture assembly.

Reality Check: For manufacturing in the Composites Lab, we as students obviously do not have the capacity to manufacture or order a bespoke fixture for the sole purpose of a final project. Thus, the team plans to utilize clamps/vises and chocks to restrict movement of the mandrel. Additionally, to create some height which will allow easy application of the prepreg on the mandrel, the team envisions placing cinder blocks and bricks on top of the autoclave cart, thus mimicking the ideal fixture assembly proposed above.

Figure 1: The Ideal Composite Fixture

2.4.4 Layup of the Prepreg

1. Before the prepreg is to be laid up on the mandrel, steps need to be taken to ensure that the alignment of the prepreg with the mandrel is accurate.
2. This is done in two ways. Post the cleanup with acetone, markings are made on the mandrel which help the personnel align the prepreg with the mandrel. Secondly, the separator paper can be used as a pressure and alignment measure relative to the mandrel as well.
3. For the first layer on the mandrel, the vacuum bag is placed. The Vacuum bag is wrapped around the entire mandrel ensuring that there is some excess length of bag lengthwise. This is to allow some space for the vacuum seal to be applied on the assembly.
4. Now, the initial layers of the prepreg are applied on the mandrel. Once the prepreg attaches to the mandrel, complete adherence is ensured by applying pressure on the separator paper layer using a tool.
5. Next, the separator paper is removed gently. The pressure applied on removing the separator paper is important because too much pressure can cause the fiber to separate, and too less pressure might maintain voids in the composite layup.
6. After every 4-6 plies, perform light vacuum debulking for 10-15 minutes. This is essential to remove voids (if any) from the composite.
7. The perforated release film and the breather cloth are applied on the assembly respectively. The breather cloth is essential to collecting the excess resin which may leak out of the prepregs during the curing process.
8. This entire setup is wrapped in a vacuum bag and then attached to a thru-bag vacuum connector and is sealed using the yellow sealant tapes.
9. A pipe is attached to the sealed assembly, and this pipe is then connected to a vacuum pump. The vacuum pump is turned on, and the assembly is finally vacuum sealed with the vacuum reaching close to 28 inHg.
10. A thorough leak check should be performed to check for any regions which may not be sealed perfectly.
11. This setup is then sent into the oven for curing.
12. Once cured and back to room temperature, the composite is removed from the mandrel slowly. This is where the chemical release agent proves its utility and allows convenient and easy removal. There is very little scope of removing the composite in one piece should it become stuck on the mandrel.
13. If possible, it is recommended that the mandrel be used again for the 2nd layup as well.
14. To adhere the core to the 1st composite layup, an epoxy adhesive is used. Alternatively, an easier method is to use an adhesive film.
15. Prior to applying the adhesive, the top surface of the cured composite is worn down with abrasive sandpaper. This is done to create microscopic grooves and increase the surface area for the adhesive to be applied over, increasing chances of clean adhesion.

16. The adhesive is mixed in a manufacturer recommended ratio of 1:1, and then uniformly applied on the surface of the composite.
17. Cure time is relatively long at 77F (6-7 hours) so personnel must take their time in ensuring that the NOMEX is adhered satisfactorily to the composite.
18. The NOMEX is placed on the composite in like how the prepreg layup was done. If required, the NOMEX core can be filled with resin as well. In the interest of weight savings, this is not done here.
19. After the NOMEX is applied, the final plies of the prepreg are applied on the assembly. The vacuum bagging process is repeated, and the entire assembly is cured in the autoclave for a second time.
20. The completed fuselage structure is now removed and prepared for finishing touches such as creating the door cutouts through a water jet facility, and then the final finishing and polishing to give the assembly a good surface finish.

### 3. Curing Procedures (Three-Stage Curing Process)

The curing approach for this project uses a step curing method because we are using a two-part epoxy adhesive to bond the Nomex® honeycomb core to the first set of cured prepreg layers.

In many sandwich structures, the face sheets and core are cured together at once by using film adhesives or by co-curing methods. However, in this project, because only a liquid epoxy adhesive was available in the lab, the first set of prepreg plies must be cured first to create a solid surface for the honeycomb core to bond to.

Using a step cure makes sure the core is properly attached and avoids trapping too much resin or air between the layers. This method also prevents weak bonding and reduces the chances of defects inside the structure.

The selected ramp rates and dwell times follow normal industry standards for epoxy-based prepregs. A slow heating rate of 2–3°C per minute avoids overheating the laminate, prevents resin from leaking out, and ensures uniform heating through the laminate thickness.

The temperatures and times chosen were based on a careful understanding of the resin behavior. The first ramp goes to 220°F (105°C) and holds for 30–45 minutes. This temperature was selected because it is high enough for the resin to begin gelling (partially solidifying), giving the layup "green strength" without causing the resin to fully cure. This is important to make the structure stable before proceeding to final cure.

After the first hold, the temperature is ramped up again to 275°F (135°C) and held for 90 minutes. This final cure temperature and time are based on the manufacturer's datasheet for the 7781 prepreg system and standard aerospace curing practices. It allows full cross-linking of the epoxy resin, achieving the desired final mechanical properties like strength and stiffness.

Cooling is done slowly under pressure (around 2°C/min) to avoid introducing residual stresses or warping in the part.

The step curing process, the chosen temperatures, and the slow ramp rates together ensure high-quality bonding of the Nomex® core and produce a structure suitable according to the requirements.

3.1 Preparation for Autoclave Curing

- The vacuum bag is checked to ensure a stable vacuum of approximately 28 inHg. A leak check should be performed by ensuring the setup holds the pressure when left for about 15 minutes, i.e. the vacuum pump pressure does not drop over time.
- The vacuum port installed on the vacuum bag connected securely to the autoclave vacuum system, ensuring that vacuum would be maintained during the heating and curing processes.
- The vacuum bagged assembly was carefully placed onto a perforated steel or aluminum tray inside the autoclave. Care was taken to avoid puncturing the bag or disturbing the layup. High-temperature supports are intended to be used where necessary to prevent deformation during curing.
- Personal protective equipment (PPE), including heat-resistant gloves, are worn during the setup process.
- All vacuum lines, thermocouples, and connectors are inspected to confirm they are properly routed and secured to avoid damage during the cycle.
- After confirming that vacuum is maintained and autoclave parameters such as temperature ramps, pressure levels, and dwell times matched the defined cure cycle, the autoclave is set up.

Following completion of setup, the curing cycle is initiated using the established two-stage ramp and hold profile.

a. Initial Skin Curing
- Autoclave external pressure (~60-85 psi) is applied before heating.
- Two- step ramp cycle is applied according to the technical data sheet of E-glass prepreg that is used.
- The first cycle is determined by the glass transition temperature of the resin.
- Dwell or hold times are provided, so that the deviation for actual and intended temperatures effects can be controlled.
- The second cure cycle is determined by the cure temperature of the resin.
- The following table provides the detailed curing cycle of the prepreg.

b. Autoclave Cure Schedule:
Step | Action | Parameters
1 | Apply vacuum and pressure | 28 in Hg vacuum, 60-85 psi pressure
2 | Ramp 1 | 2-3°C/min to 220°F (105°C)
3 | Hold 1 | Hold at 220°F for 30-45 minutes (gelation stage)
4 | Ramp 2 | 2-3°C/min to 275°F (135°C)
5 | Hold 2 | Hold at 275°F for 90 minutes (full cure)
6 | Cool Down | 2°C/min to room temperature under pressure

3.2 Finishing Techniques

After the final autoclave cure and full cooling, the part undergoes several finishing steps to achieve the required surface quality and dimensions:

1. Demolding:
- Carefully remove all vacuum bagging materials.
- Gently demold the fuselage using plastic or Teflon wedges to avoid surface damage.
2. Flash and Resin Trim:
- Excess resin bleed-outs and flashing along the edges are removed using a diamond-coated bandsaw or abrasive cutoff wheels.
3. Surface Sanding:
- Light sanding is carried out using 320 to 600 grit sandpaper.
- Initial sanding is performed dry to remove surface imperfections.
- Wet sanding may be used afterward to achieve a smoother finish and to minimize dust.
4. Surface Cleaning:
- After sanding, the surface is cleaned using compressed air and lint-free wipes with isopropyl alcohol to remove sanding debris.
5. Dimensional Inspection:
- Critical dimensions such as outer diameter, inner diameter, and wall thickness are measured to confirm conformity to design specifications.
6. Cutout Creation:
- According to the design report, specific cutouts and access features must be introduced into the structure.
- To achieve precise, clean cuts without damaging the composite layers, water jet cutting is selected as the preferred method.
- The cured fuselage tube is positioned securely on the water jet table.
- Cutouts are programmed into the CNC water jet system following the CAD drawings.
- A fine abrasive stream is used to make clean and accurate openings without delaminating the composite laminate.
7. Final Surface Preparation:
- If needed, additional minor sanding and polishing are performed around the cutout edges to remove burrs.
- A final wipe-down with alcohol ensures the part is ready for structural testing or assembly.

These finishing techniques ensure that the manufactured fuselage not only meets the mechanical performance requirements but also presents a high-quality surface and dimensional accuracy, as expected in aerospace-grade components.

3.3 Testing Plan

Mechanical Testing:

| ● Flexural Testing: ○ ASTM D790 — Standard Test Methods for Flexural Properties of Plastics. ○ Conduct 3-point bend tests to determine flexural modulus and strength.
3.4 | Void Content Analysis ● Void Measurement: ○ ASTM D2734 — Standard Test Methods for Void Content of Reinforced Plastics. ○ Resin burn-off or optical microscopy cross-sectional analysis.
3.5 | Post Failure Analysis ● Post-failure microscopy (optical or SEM) to identify failure modes

### 4. Risk and Mitigation Strategies for Vacuum Bagging

### 4.1 Introduction to Risk Management in Vacuum Bagging

The vacuum bagging process is a cornerstone in the manufacturing of advanced composite structures for aerospace applications, valued for its ability to produce high-quality laminates with improved fiber volume fraction, reduced void content, and consistent mechanical properties.[6] However despite its advantages over traditional methods like hand layup, vacuum bagging comes with unique risks that can compromise structural integrity and reliability if not properly mitigated. These risks are particularly significant in the context of aerospace fuselage manufacturing, where even minor defects can lead to catastrophic failure.[7]

Research has shown that the quality and performance of vacuum-bagged composite parts are highly sensitive to process parameters such as vacuum pressure, temperature, and resin flow. For instance, Haschenburger (2023) [8] demonstrated that vacuum bag leaks, uneven pressure, and environmental fluctuations are leading contributors to porosity, resin-rich or resin-starved areas, and delamination. Similarly, Mujahid et.al (2020) [9] found that variations in vacuum pressure and bag integrity during consolidation directly affect fiber alignment and void content, resulting in significant reductions in interlaminar shear strength and fatigue life.

Given these challenges, the aerospace industry emphasizes a systematic approach to risk management, involving the identification of key process risks, quantitative assessment of their likelihood and impact, and the implementation of evidence-based mitigation strategies.

In this section, we systematically identify the most critical risks associated with vacuum bagging for composite fuselage manufacturing, assess their probability and potential consequences using a 5x5 risk matrix, and propose mitigation strategies grounded in empirical research and industry standards. This analysis is essential for ensuring not only the structural performance of the manufactured fuselage but also compliance with the aerospace standards.

### 4.2 Identification of Key Risks:

4.2.1 Vacuum bag leaks or seal Failures:

Vacuum bag leaks or seal failures arise when the vacuum bag's integrity is compromised, permitting air to enter the bagged assembly during resin infusion or curing. This intrusion disrupts the critical pressure differential required for laminate compaction, causing inadequate air removal, diminished consolidation, and elevated void content in the resulting composite component. Even small leaks can substantially impact the internal pressure distribution, weakening the effectiveness of the vacuum process [8].

Research by Haschenburger (2023) [8] indicates that vacuum bag leaks, particularly those creating a direct connection between the laminate and external environment, represent some of the most significant contributors to porosity and quality degradation in aerospace composite manufacturing. The study emphasizes that the manual procedures involved in vacuum bag preparation and leak testing cause this stage to be highly dependent on operator proficiency. Consequently, numerous quality issues and process uncertainties originate here. Industrial experience also verifies that vacuum bag leaks are a primary reason for scrapped parts and rework, prompting the growing implementation of advanced leak detection methods, such as ultrasonic techniques, for quality assurance.

Immediate Consequences: Components affected by vacuum leaks frequently show elevated void content and inadequate fiber wet-out, resulting in non-compliance with mechanical property specifications. This issue typically leads to scrapping or extensive rework of parts.

Downstream Consequences: Elevated void content decreases interlaminar shear strength and fatigue life, potentially causing premature structural failure during service or failure to satisfy aerospace certification standards.

4.2.2 Uneven Pressure Distribution:

Uneven pressure distribution occurs due to incorrect placement of breather materials, wrinkles in the vacuum bag, or geometric complexity of the mold. These issues can lead to localized differences in compaction pressure, causing resin-rich or resin-starved areas, fiber misalignment, and variations in laminate thickness [10].

Studies by Ma et al. (2020) [10] indicate that complex geometries and sharp corners are particularly vulnerable to uneven pressure distribution during vacuum bag-only prepreg processing. This can result in microstructural defects, including corner thinning, warpage, and dimensional inconsistencies. The research underscores that these pressure irregularities are significant contributors to defects in contoured aerospace laminates, recommending debulking procedures and mold design modifications to address these challenges.

Immediate Consequences: Localized flaws such as resin pooling, dry areas, and thickness variations often require rework or lead to scrapped parts [10].

Downstream Consequences: The resulting stress concentrations and fiber misalignment reduce load‑bearing capacity, heighten the risk of delamination, and undermine the fuselage’s long‑term durability [10].

4.2.3 Resin Pooling and Dry Spots:

Resin pooling denotes localized accumulations of excess resin, whereas dry spots are regions where the fibers are insufficiently wetted. Both defects generally arise from suboptimal resin‑flow paths, improper port placement, or inadequate working time during infusion—conditions that become more pronounced in large or complex layups.

According to the CKN Knowledge in Practice Centre, all liquid composite molding (LCM) processes—including vacuum bagging—are vulnerable to flow‑induced dry spots and pooling. These flaws are commonly traced to poor flow strategies, race tracking (where resin bypasses fiber regions), or premature resin gelation, and are well documented in industrial practice as principal sources of variability in composite part quality.

Immediate Consequences: Regions with dry spots or resin pooling frequently fail initial quality inspections, necessitating localized repairs or leading to part rejection.

Downstream Consequences: Insufficient fiber wet‑out or excessive resin content lowers interlaminar strength and stiffness, heightening the likelihood of delamination and structural failure under service loads.

4.2.4 Voids and Porosity:

Voids are air pockets or trapped gas regions within the laminate that originate from entrained air during layup, dissolved moisture in the resin, or insufficient evacuation during vacuum application. Porosity exceeding 1–2 % markedly degrades the mechanical properties of composite laminates [11].

Recent studies demonstrate that both interlaminar and intralaminar void content rises sharply when porosity surpasses 1.5–2.0 %, typically due to inadequate vacuum pressure or moisture absorption during processing. These voids serve as crack‑initiation sites and weaken the fiber–matrix interface, as verified by ultrasonic C‑scan and metallographic analyses of aerospace‑grade carbon/epoxy laminates [11].

Immediate Consequences: Elevated void content reduces short‑beam shear strength and flexural
modulus, | frequently | causing | parts | to | fail | mechanical | property | tests | [11].
Downstream Consequences: Voids accelerate crack growth and moisture ingress, thereby shortening fatigue life and diminishing the long‑term durability of fuselage structures [11].

4.2.5 Environmental Factors (Temperature and Humidity Variations)

Fluctuations in ambient temperature and humidity during layup and curing can modify resin viscosity, alter cure kinetics, and change the final cross‑link density. Elevated humidity also promotes moisture uptake by the resin, increasing void formation and lowering the glass‑transition temperature.

Aerospace polymers experience wide swings in temperature and humidity both during manufacture and in service. Studies show that uncontrolled environmental conditions can induce microcracking, elevate moisture absorption, and diminish stiffness and strength in composite structures—effects that are especially pronounced in large, non‑autoclave‑cured laminates.

Immediate Consequences: Variable cure, warpage, or incomplete polymerization often necessitate rework or result in part rejection.
Downstream Consequences: Increased moisture uptake and microcracking reduce long‑term structural stability and mechanical performance, potentially complicating certification of the fuselage.

4.2.6 Staggering-Induced Stress Concentrations

Staggering refers to the deliberate offsetting of ply terminations in composite laminates to prevent continuous seams, which could otherwise serve as planes of weakness. However, improper staggering—characterized by insufficient gap widths, irregular stagger patterns, or abrupt ply drops—introduces localized geometric discontinuities. These discontinuities disrupt stress flow and lead to elevated strain concentrations (εₘₐₓ) and stress concentration factors (Kₜ) like those
found | around | holes | or | notches | [16].
Gaps between staggered ply ends create resin-rich zones with reduced fiber reinforcement. Under tensile or bending loads, these zones exhibit higher strains due to the stiffness mismatch between resin and fibers. For instance, Cairns et al. (1999) showed that gaps as small as 0.06 in. (1.5 mm) in a [0°] laminate increase strain concentrations by 12–18 % compared to a nominal, ungapped laminate.

Immediate Consequences: Premature matrix cracking during proof loading, leading to rework or part rejection. Failure to comply with ASTM D7137 (Compressive After Impact) standards due to localized weaknesses.

Downstream Consequences: Reduced fatigue life, with up to a 50 % decrease under cyclic loading caused by crack propagation at gap sites. Certification delays resulting from non-destructive evaluation (NDE) findings, such as ultrasonic detection of delamination.

### 4.3 Risk Assessment Methodology

A systematic, quantitative risk‑assessment methodology is essential for ensuring the reliability and safety of composite‑fuselage manufacturing, particularly when vacuum bagging is employed. Accordingly, this work adopts the 5 × 5 risk matrix, a structured and widely recognized framework for evaluating and prioritizing process risks by likelihood and impact.

4.3.1 5×5 Risk Matrix Framework

The 5×5 risk matrix is both a visual and analytical tool that allows teams to assess, compare, and prioritize risks by assigning each one a score across two axes: Likelihood (Probability) and Impact (Severity/Consequence). This degree of granularity enables a more detailed understanding of risk than simpler 3×3 or 4×4 matrices, which is particularly valuable in high-stakes aerospace manufacturing settings.

Likelihood (Probability) Scale

Score | Descriptor | Definition
1 | Rare | Unlikely to occur; may happen only under exceptional circumstances.
2 | Unlikely | Possible but not anticipated; has occurred in other contexts but not in this process.
3 | Moderate | Could occur occasionally; has been observed at times in similar processes.
4 | Likely | Expected under most conditions; has occurred repeatedly.
5 | Most Likely | Anticipated in most cases, occurs frequently or continuously.

Impact (Severity/Consequence) Scale

Score | Descriptor | Definition
1 | Insignificant | No measurable impact on part quality or safety; negligible effect on cost or schedule.
2 | Minor | Requires minor rework; does not significantly affect performance or regulatory compliance.
3 | Moderate | Noticeable degradation in part quality may necessitate substantial rework or result in limited failure.
4 | Major | Significant functional loss or non-compliance; part may be scrapped or require major rework.
5 | Severe | Catastrophic failure resulting in loss of structural integrity or safety poses a risk to program success or certification.

Risk Rating Calculation

Each identified risk is assigned to a Likelihood and Impact score based on process knowledge, literature, and historical data. The Risk Rating is then calculated as:

Risk Rating = Likelihood X Impact

- 1–4: Acceptable (Low Risk)
- 5–9: Adequate (Monitor)
- 10–16: Tolerable (Mitigation Required)
- 17–25: Unacceptable (Immediate Action Required)

Color coding is used in the matrix to visually distinguish risk levels: green (low), yellow (moderate), orange (significant), and red (critical)

4.3.2 Risk Assessment Table

The table below provides a structured assessment of the key risks associated with vacuum bagging in composite fuselage manufacturing. Each risk is evaluated using the 5×5 risk matrix framework, which assigns numerical values to both likelihood (probability of occurrence) and impact (severity of consequences) on a scale from 1 (lowest) to 5 (highest). The overall risk score is determined by multiplying likelihood and impact, supporting the prioritization of mitigation strategies.

Risk | Likelihood | Impact | Risk Score | Justification
Vacuum Bag leaks | 4 | 5 | 20 | Manual setup and leak testing are operator-dependent; leaks can cause scrapped parts or certification failure.
Uneven Pressure Distribution | 4 | 4 | 16 | Complex fuselage sections are vulnerable; leads to stress concentrations and rework
Resin Pooling/Dry spots | 3 | 3 | 9 | Operator experience and process design are key; can cause part rejection or localized repair
Voids and Porosity | 3 | 4 | 12 | Voids >2% can reduce shear strength by 10% per percent void; frequent in vacuum bag-only processes
Environmental Factors | 3 | 2 | 6 | Workshop conditions and lack of environmental control can lead to process variability and part inconsistency
Staggering/Ply Drops | 3 | 4 | 12 | NASA and recent studies show ply drops are critical sites for delamination and strength loss

Risk Matrix Visualization:

Impact → Likelihood ↓ | Very Low (1) | Low (2) | Medium (3) | High (4) | Very High (5)
Almost Certain (5) | | | | Leaking of Vacuum bag/Imperfect Seal
Likely (4) | | | | Uneven Pressure
Probable (3) | | Environmental factors | Resin Pooling | Voids and Porosity Staggering

Unlikely (2)

Very Unlikely (1)

Interpretation:

Vacuum bag leaks represent the most critical risk (score: 20) and require immediate and robust mitigation measures.

Uneven pressure distribution, Staggering and voids/porosity are classified as significant risks (scores: 12), necessitating focused process control strategies.

Resin pooling/dry spots and environmental factors are identified as moderate risks (scores: 9), highlighting the need for ongoing monitoring and procedural refinement.

This structured risk assessment facilitates the targeted allocation of resources and implementation of process controls, directly supporting the quality, safety, and certification requirements of composite fuselage manufacturing.

### 5. Integration of FMEA Methodology for Enhanced Risk Management

Failure Mode and Effects Analysis (FMEA) is a structured, quantitative method used to prioritize risks in composite fuselage manufacturing by assessing three key dimensions: Severity (S), Occurrence (O), and Detection (D). This approach is consistent with aerospace regulatory standards (FAA, EASA) and offers a systematic framework for identifying failure modes, evaluating their effects, and implementing targeted mitigation strategies. The following section presents the integration of FMEA into the vacuum bagging risk assessment, drawing on academic research and established industry practices.

### 5.1 FMEA Framework for Composite Fuselage Manufacturing

FMEA Scales:

Severity | Score | Occurrence | Score | Detection | Score
Insignificant (No impact) | 1 | Rare (<1% probability) | 1 | Almost Certain Detection | 1
Minor (Aesthetic defect) | 2 | Unlikely (1–10%) | 2 | High Likelihood of Detection | 2
Moderate (Rework needed) | 3 | Possible (10– 30%) | 3 | Moderate Detection | 3
Major (Structural defect) | 4 | Likely (30–60%) | 4 | Low Likelihood of Detection | 4
Catastrophic (Part scrap) | 5 | Almost Certain (>60%) | 5 | Very Unlikely Detection | 5

Risk Priority Number (RPN):

RPN = S×O×D (Range: 1–125)

FMEA Table for Vacuum Bagging Risks

Risk | Failure Mode | S | O | D | RPN | Mitigation strategies
Vacuum bag leaks | Air ingress → voids (Vf >2%) | 5 | 4 | 3 | 60 | - Automated leak detection (ultrasonic/pressure decay sensors)
| → Reduced interlaminar shear strength | | | | | Redundant sealing (double tape + silicone at joints)
Uneven Pressure | Localized resin pooling/dry spots | 4 | 3 | 3 | 36 | - Pressure mapping sensors + flow simulation (ANSYS/PAM-RTM
| → Delamination under bending loads | | | | | - Standardized breather layout SOPs
Resin Pooling/Dry Spots | Incomplete fiber wet-out | 3 | 3 | 2 | 18 | - Resin flow simulation + metered dispensing systems
| → 15–20% strength reduction | | | | | - In-process visual inspection (transparent bagging films)
Environmental Factors | Cure kinetics variability | 3 | 3 | 4 | 36 | - Climate-controlled workspace (20–25°C, <60% RH)
| → Residual stresses/warpage | | | | | - Resin selection with extended pot life (Hexcel RTM6)
Staggering/Ply Drops | Improper ply staggering or abrupt ply drops | 3 | 3 | 3 | 27 | Optimized stagger patterns (Fibonacci sequence)

| - Laser-guided ply placement

### Local stress concentrations (σmax≥1.5nom max≥1.5σnom), delamination, reduced CAI strength

### 5.2 Key Findings from FMEA

Critical | Risks | (RPN | ≥ | 40):

### Vacuum bag leaks (RPN = 60) demand immediate mitigation due to their high severity (S =

5) and likelihood (O = 4). Implementation of automated leak detection systems significantly improves detectability (D = 3 → 1), thereby reducing the RPN to 20.

### Haschenburger (2023) demonstrated that automated leak detection reduces void content by

15–20 % in aerospace-grade laminates.

Moderate | Risks | (RPN | 20–39):
Uneven pressure distribution (RPN = 36) can be effectively mitigated through the use of pressure sensors and simulation-based optimization of breather placement, in accordance with findings by Ma et al. (2020) [10].
Low | Risks | (RPN | ≤ | 19):
Resin pooling (RPN = 18) is addressed through flow simulation and comprehensive operator training, as recommended by the CKN Knowledge in Practice Centre (2021).

### 5.3 Continuous Improvement via FMEA

Integrating Failure Mode and Effects Analysis (FMEA) into composite fuselage manufacturing provides a structured methodology for risk management and process optimization [12]. The following expanded framework outlines a pathway for continuous improvement, supported by academic literature and industrial case studies.[13]

5.3.1 Data-Driven FMEA Updates

A data-driven FMEA approach ensures that risk assessments remain dynamic, adapting to real-world manufacturing outcomes. Through systematic collection and analysis of process and quality data, organizations can deepen their understanding of failure modes and adjust risk priorities accordingly.

Implementation:

a. Root Cause Analysis (RCA):

Post-process inspection data, such as ultrasonic C-scan maps identifying voids and porosity, are correlated with FMEA entries. Haschenburger (2021) demonstrated that linking vacuum pressure logs to defect locations enabled targeted enhancements in leak detection, resulting in a 15–20 % reduction in porosity in aerospace laminates [12].

b. Dynamic RPN Adjustment:

Severity, Occurrence, and Detection scores within the FMEA are updated routinely (e.g., quarterly) based on defect trends and process monitoring data. This dynamic approach aligns with advanced manufacturing risk prioritization frameworks. Hickmott et al. (2020) showed that refining process windows using porosity modeling and experimental results led to measurable improvements in composite part quality [13].

c. Workflow:

Defect data from NDE reports are mapped to FMEA failure modes through Pareto analysis, ensuring that high-priority risks are addressed with targeted mitigation measures [13].

By maintaining a data-driven FMEA, manufacturers ensure that risk management strategies are continuously refined, directly supporting reductions in defect rates and improvements in composite part quality [12]

5.3.2 Closed-Loop Feedback Systems

Closed-loop feedback mechanisms ensure that insights gained from automated process monitoring and operator experience are systematically integrated into the FMEA and corresponding risk mitigation strategies.

Implementation:

a. Operator-Driven Improvements:

Shop-floor feedback is regularly incorporated into FMEA updates. Ma et al. (2014) demonstrated that addressing operator-reported issues related to breather cloth alignment improved pressure uniformity, thereby reducing resin-rich zones and surface porosity [14].

b. Cross-Functional Reviews:

Routine FMEA review meetings—held monthly and involving design, manufacturing, and quality assurance teams—facilitate the discussion of defect trends and process improvements. This practice is widely recommended in advanced manufacturing literature [13].

c. Automated Data Integration:

IoT-enabled sensors monitoring parameters such as vacuum, temperature, and resin flow continuously feed real-time process data into FMEA systems. Haschenburger (2021) showed that integrating volumetric flow rate and infrared thermography data enhanced leak localization and reduced corrective action response times.

Closed-loop feedback ensures that both process data and human expertise are utilized to drive continuous risk reduction, promoting a culture of shared responsibility and sustained process improvement.

5.3.3 Integration with Lean and Digital Methodologies

Integrating FMEA with Lean, Six Sigma, and digital manufacturing methodologies enhances its effectiveness by embedding risk management within broader initiatives focused on quality and operational efficiency.

Implementation:

a. Six Sigma DMAIC:

FMEA supports the identification of critical-to-quality (CTQ) parameters and prioritization of process improvements, as demonstrated in aerospace applications by Ma et al. (2014) [14].

b. Statistical Process Control (SPC):

Detection controls defined in the FMEA are linked to SPC chart limits, enabling early identification of process drift and facilitating prompt corrective actions.

c. Digital Twin Integration:

Digital twins of the composite cure process can be integrated with FMEA to enable real-time risk assessment and virtual testing of mitigation strategies. Hickmott et al. (2020) demonstrated that digital modeling of porosity evolution informs FMEA updates and guides process window refinement [13].

Integrating FMEA with Lean and digital methodologies ensures that risk management remains proactive, data-driven, and aligned with best practices in advanced aerospace manufacturing.

d. Certification-Driven Improvement Cycles

Aligning FMEA updates with certification milestones ensures that risk management practices remain compliant with evolving regulatory requirements and industry standards.

Implementation:

a. Pre-Certification:

FMEA gap analyses are performed in accordance with FAA and EASA requirements, and detection controls are established for critical failure modes.

b. Post-Certification Monitoring:

In-service failures and audit findings inform updates to FMEA severity scores, with revised documentation submitted as part of annual review processes [13].

Certification-driven FMEA cycles ensure that risk management remains both proactive and adaptive, reinforcing ongoing compliance and enabling continuous process improvement across the entire product lifecycle.

Continuous improvement through FMEA is achieved by integrating process data, operator input, Lean and digital methodologies, and certification requirements into a dynamic risk management framework. This approach reduces defect rates, enhances product quality, and ensures both regulatory compliance and operational excellence in composite fuselage manufacturing.

### 6. Mitigation Strategies for Key Risks in Vacuum Bagging

The following section outlines evidence-based mitigation strategies for the principal risks identified in the vacuum bagging process used in composite fuselage manufacturing. Each strategy is derived from current research literature and established industry best practices, aiming to reduce both the likelihood and impact of process-related failures.

6.1 | Vacuum Bag Leaks or Failures
Automated | | Leak | | Detection:
Implement automated leak detection systems, such as ultrasonic sensors or real-time pressure decay monitoring, to identify and localize leaks prior to resin infusion. Haschenburger (2023) emphasizes that advanced leakage detection methods, including those incorporating machine learning significantly enhance the reliability of vacuum bagging and reduce porosity, particularly in aerospace applications [8].
Redundant | Sealing | and | Pre-Engineered | Kits:
Utilize double-seal tape systems and apply silicone sealant at critical joints and corners. Both Haschenburger (2023) and operational practices at Airbus Operations GmbH underscore that redundant sealing and the use of pre-cut bagging kits effectively minimize operator error and lower the likelihood of vacuum leaks [8].
Operator | Training | and | Standardization:
Establish standardized vacuum bagging procedures and deliver comprehensive operator training. Haschenburger (2023) notes that manual execution and leak detection are highly dependent on operator skill, with many quality issues originating at this stage. Therefore, structured training and procedural standardization are essential [8].

### 6.2 Uneven Pressure Distribution

Optimized | Breather | and | Bagging | Schedule:
Utilize computer-aided flow simulation to design optimal breather and flow media layouts that promote uniform pressure distribution, particularly in geometrically complex parts. Ma et al. (2020) show that strategic breather placement and a well-planned bagging schedule significantly reduce pressure gradients and related defects in contoured aerospace laminates [10].
Real-Time | | Pressure | | Monitoring:
Incorporate distributed pressure sensors within the vacuum bag to monitor compaction pressure throughout the cure cycle. Ma et al. (2020) advocate for real-time pressure monitoring as a critical quality assurance measure, particularly for identifying and correcting inconsistencies in complex components [10].

Standard | | Operating | | Procedures | (SOPs):
Establish and enforce SOPs for breather placement and vacuum bagging to reduce operator-dependent variability and ensure process consistency. This approach is supported by findings from both Ma et al. (2020) [10] and Haschenburger (2023) [8]

### 6.3 Resin Pooling/Dry Spots

Resin | Flow | Simulation | and | Port | Optimization:
Perform resin flow simulations to optimize the placement of inlet and outlet ports, minimizing the likelihood of race tracking or incomplete wet-out. Both Ma et al. (2020) and CompositesWorld (2025) emphasize that simulation-driven design effectively prevents dry spots and resin pooling [10].
Controlled | Resin | Application:
Utilize metered resin mixing and dispensing systems to maintain consistent resin viscosity and flow rates during infusion, thereby reducing the risk of localized resin excess or deficiency. This practice is standard in advanced composites manufacturing.
In-Process | Visual | Inspection:
Apply transparent bagging films and conduct in-process visual inspections to track resin front progression and detect potential dry spots during infusion. This approach aligns with the best practices outlined in CompositesWorld (2025)

### 6.4 Voids and Porosity

Pre-Layup | Drying | and | Vacuum | Hold:
Dry fibers and core materials in a controlled environment prior to layup and apply a vacuum hold or soak period before resin infusion to remove trapped air and dissolved gases. Ghiorse (1993) and Abraham et al. (2018) report that each 1 % increase in void content can reduce interlaminar shear strength by 7–10 %, underscoring the importance of void minimization [15].
Post-Cure | | Non-Destructive | | Evaluation | (NDE):
Employ ultrasonic C-scan or X-ray CT after curing detecting and quantify voids, enabling targeted rework or rejection of nonconforming parts. This method is a standard quality assurance and control practice in aerospace composites manufacturing [15].

### 6.5 Environmental Factors

Climate-Controlled | | | | Workspace:
Maintain a controlled manufacturing environment with active temperature and humidity regulation to ensure consistent resin cure kinetics and reduce environmental variability. Both Haschenburger (2023) [8] and Ma et al. (2020) [10] highlight the critical role of environmental control in maintaining process consistency and part quality.
Resin | Selection | and | Pot | Life:
Choose resin systems with suitable pot life and cure characteristics for the prevailing environmental conditions to mitigate the risk of incomplete curing or premature gelation. This practice is widely recommended in composites processing literature.
Process | | | | Documentation:
Log environmental conditions during each manufacturing cycle to support traceability and facilitate root cause analysis in the event of defects. This approach is endorsed in both academic research and industry standards.

Staggering-Induced Stress Concentrations

Optimized Stagger Design:

Maintain minimum gap widths of 10× the ply thickness (e.g., 2 mm for 0.2 mm plies) to promote even stress distribution. Apply nonlinear stagger patterns (e.g., Fibonacci sequence) to prevent resonant stress accumulation.

Process Controls:

Utilize laser projection systems to achieve precise ply alignment within a ±0.5 mm tolerance. Perform in-process shearography to detect resin-rich zones prior to curing.

Material Adjustments:

Employ toughened epoxy resins (e.g., Hexcel® M21) with 50 % higher fracture toughness to mitigate matrix cracking. Introduce thin adhesive interlayers at stagger transitions to reduce interlaminar shear stresses.

### 6.6 Summary

This manufacturing report presents a comprehensive, research-based risk management strategy for the vacuum bagging process in composite fuselage fabrication. By systematically identifying, evaluating, and mitigating key process risks—such as vacuum bag leaks, uneven pressure distribution, resin pooling, void formation, and environmental variability, the report illustrates how evidence-based methodologies can be effectively integrated into advanced aerospace manufacturing.

The application of the 5×5 risk matrix and FMEA methodology enabled prioritization of risks based on their likelihood and impact, ensuring that the most critical threats to structural integrity and certification compliance were addressed first. Mitigation strategies were informed by current research and industry best practices, including automated leak detection systems [Haschenburger, 2023], simulation-optimized breather and resin flow layouts [Ma et al., 2020], real-time process monitoring, and climate-controlled environments. Continuous improvement was embedded through data-driven FMEA updates, closed-loop feedback, and integration with Lean and digital
manufacturing | methodologies, | consistent | with | both | academic | and | industrial
frameworks [Hickmott et al., 2020; Ma et al., 2014].

Monitoring and review protocols such as in-process sensor arrays, non-destructive evaluation (NDE), and detailed data logging ensure that risk mitigation remains effective and adaptive throughout the production cycle. This integrated approach not only reduces defects and material waste but also reinforces regulatory compliance and operational excellence in composite fuselage manufacturing.

### 7. Bill of Materials

Part
Number

Main
Assembly | Component Name | QTY. | Remarks
1 | Fuselage Components | E-Glass Prepreg | 10 Yards | Substituted for S-Glass Prepreg due to Cost and Availability
2 | | NOMEX Core | 1 Yard
F1 | Fixture Components | Mandrel | 1 | Is an Aluminum Tube of OD 5.5”
F2 | | Fixture Stands | 2 | Support the Weight of the Tube
F3 | | Closure Clamps | 2 | Help in Restricting Movement
C1 | Oven | 1 | Will be placed in an Autoclave
C2 | Autoclave Stand | 1 | Stand on which the Composite assembly will be placed
C3 | Chemical Release Agent | 1 | Applied on the Mandrel for convenient release of composite post-cure
C4 | Sealing Tape | 1 | Used to completely seal the package to induce vacuum
C5 | 2-Part Adhesive Epoxy Resin | 1 | Utilized to adhere the core to the composite

Curing
Equipment

C6 | Vacuum Bag | 4 | Each cure requires 2 layers of bags.
C7 | Breather Cloth | 2
C8 | Bleeder Cloth | 2
C9 | Vacuum Bagging Kit | 1 | Includes a Thru-Bag Connector, The vacuum pump, tubes, sealant tapes, and pressure valves among other relevant parts.
M1 | Gloves | 12 | Extra Capacity is necessary to comply with safety requirements
M2 | Safety Glasses | 4
M3 | Aprons/Lab Coats | 4
M4 | Precision Cutter | 4 | Multiple Cutters can expedite the Manual Cutting process depending on manpower
M5 | Water Jet Machine | 1 | For generating the Door Cutouts
M6 | Acetone Solution | 1 | For Cleaning
M7 | Swabs/Applicator Cloth | 5

Miscellaneous
Equipment

### 8. References

[1]. Prepreg Processing Science and EngineeringK. J. AHN and JAMES C. SEFERIS

[2]. Ridgard C. Out of autoclave composite technology for aerospace, defense and space structures. In: Proc. SAMPE 2009 Conf. Baltimore, MD: Society for the Advancement of Materials and Process Engineering, 2009, pp.1–15.

[3]. Curing Pressure Influence of Out-of-Autoclave Processing on Structural Composites for Commercial Aviation

[4] Bahksheshi, R., Pahlevanzadeh, F., et al., 2021. Additive manufacturing of polymer matrix composites. In: Brabazon, D. (Ed.), Encyclopedia of Materials: Composites. Oxford: Elsevier. vol. 1, pp. 1013–1028.
[5] Singh, J., et al., 2021. Processing of polymers and their composites: A review. In: Brabazon,
D. (Ed.), Encyclopedia of Materials: Composites. Oxford: Elsevier. vol. 2, pp. 577–603.
[6] “Vacuum Bagging Techniques: A Guide to the Principles and Practical Application of Vacuum Bagging for Laminating Composite Materials with WEST SYSTEM ® Epoxy,” 1990.
[7] Rocha, H., Rocha, A., Malheiro, J., Sousa, B., Vilela, A., Carneiro, F., and Antunes, P., “Development and Manufacturing of a Fiber Reinforced Thermoplastic Composite Spar Produced
by | Oven | Vacuum | Bagging,” | Polymers, | Vol. | 16, | No. | 15, | 2024.
https://doi.org/10.3390/polym16152216
[8] Haschenburger, A. I., “Influence and Detection of Vacuum Bag Leakages in Composites Manufacturing,” Citation, 2022. https://doi.org/10.4233/uuid:03637286-f682-4602-9890-2ac1c0102599
[9] Mujahid, Y., Sallih, N., Mustapha, M., Abdullah, M. Z., and Mustapha, F., “Effects of Processing Parameters for Vacuum-Bagging-Only Method on Shape Conformation of Laminated Composites,” Processes, Vol. 8, No. 9, 2020. https://doi.org/10.3390/PR8091147
[10] Ma, Y., Centea, T., and Nutt, S. R., “Defect Reduction Strategies for the Manufacture of Contoured Laminates Using Vacuum BAG-Only Prepregs,” Polymer Composites, Vol. 38, No. 9, 2017, pp. 2016–2025. https://doi.org/10.1002/pc.23773
[11] Shi, J., Wang, W., Liu, F., Xun, G., and Yang, P., “Effects of Porosity on Ultrasonic Attenuation Coefficient, Shear Properties and Failure Mechanisms of CF/EP Laminates,” Heliyon, Vol. 10, No. 3, 2024. https://doi.org/10.1016/j.heliyon.2024.e25288

[12] Haschenburger, A., Menke, N., and Stüve, J., “Sensor-Based Leakage Detection in Vacuum Bagging,” International Journal of Advanced Manufacturing Technology, Vol. 116, Nos. 7–8, 2021, pp. 2413–2424. https://doi.org/10.1007/s00170-021-07505-5
[13] Hickmott, C., Forghani, A., Hutten, V., Lorbiecki, E., Palmieri, F., Grimsley, B., Coxon, B., Fernlund, G., and Poursartip, A., “A NUMERICAL AND EXPERIMENTAL APPROACH FOR MODELING POROSITY DUE TO ENTRAPPED AIR AND VOLATILES OFF-GASSING DURING MANUFACTURING OF COMPOSITE STRUCTURES.”
[14] Bloom, L. D., Napper, M. A., Ward, C., and Potter, K., “A STUDY OF THE PRESSURE DISTRIBUTION IN THE HAND LAYUP AND VACUUM BAGGING PROCESSES,” 2014.
[15] Pishvar, M., Amirkhosravi, M., and Altan, M. C., “Magnet Assisted Composite Manufacturing: A Flexible New Technique for Achieving High Consolidation Pressure in Vacuum Bag/Lay-up Processes,” Journal of Visualized Experiments, Vol. 2018, No. 135, 2018. https://doi.org/10.3791/57254
[16] Payne, N., “Stress Concentrations in a Fiber Reinforced Composite Containing Stress Concentrations in a Fiber Reinforced Composite Containing Functionally Graded Fibers Functionally Graded Fibers Stress Concentrations in a Fiber Reinforced Composite Containing Functionally Graded Fibers,” 2020.
